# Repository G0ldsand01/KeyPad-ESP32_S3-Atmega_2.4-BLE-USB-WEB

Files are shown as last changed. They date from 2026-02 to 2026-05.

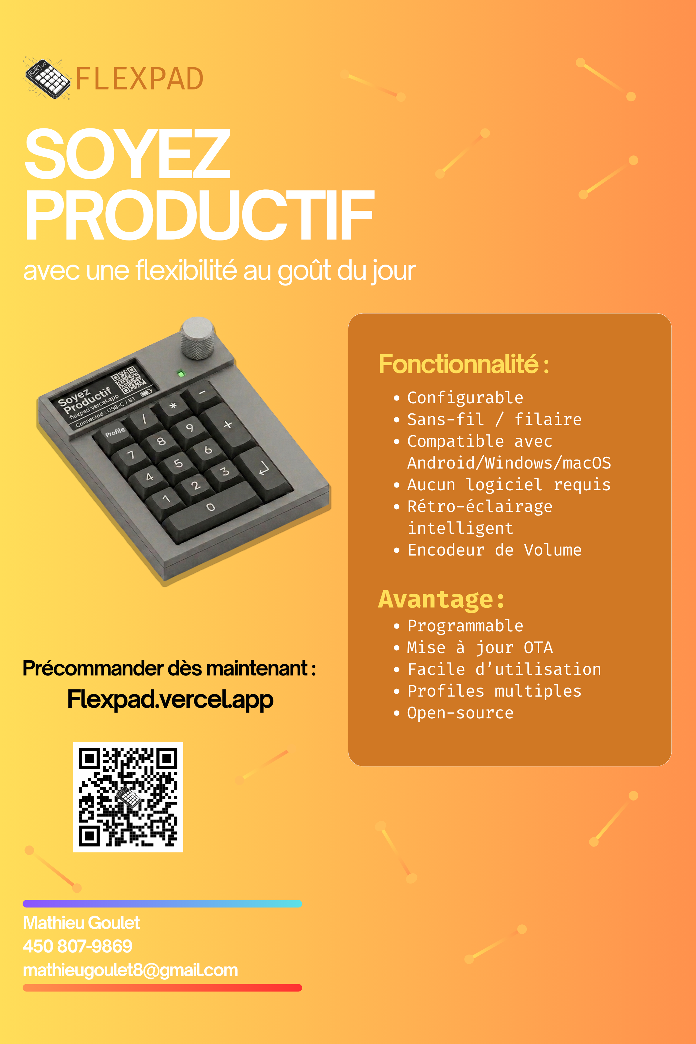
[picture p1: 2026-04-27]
public/images/Affiche.png

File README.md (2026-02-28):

# Macropad — Pavé numérique configurable

Projet de pavé numérique personnalisable avec ESP32-S3 et ATmega328P, configurable via une interface web moderne (Web Serial / Web Bluetooth).

## 📁 Structure du projet

```
Projet_Final/
├── README.md                 # Ce fichier — vue d'ensemble
├── docs/
│   └── FONCTIONNALITES.md    # Description détaillée des fonctions
├── firmware/                 # Code Arduino (ESP32) et C++ (ATmega)
│   └── README.md             # Guide firmware
├── PCB/                      # Schémas et circuits imprimés KiCad
│   └── README.md             # Documentation PCB
├── public/
│   ├── scripts/main.js       # Logique principale de l'interface
│   └── styles/global.css     # Styles CSS
├── src/
│   ├── components/           # NumpadGrid, ConfigPanel, BacklightPanel, SettingsPanel, etc.
│   ├── layouts/
│   └── pages/
├── package.json
└── astro.config.mjs
```

## 🚀 Démarrage rapide

### Interface web

```bash
pnpm install
pnpm dev
```

Ouvrez `http://localhost:4321`

### Connexion au Macropad

- **USB** : Sélectionnez "Wired (USB)" → Connecter → Choisir le port série
- **Bluetooth** : Sélectionnez "Bluetooth (ESP32)" → Connecter → Choisir l'appareil

### Firmware

Voir [firmware/README.md](./firmware/README.md) pour compiler et flasher l'ESP32 et l'ATmega.

## ✅ Ce qui fonctionne actuellement

| Fonctionnalité | Statut |
|---|---|
| Configuration des touches (simple, modificateur, média, macro) | ✅ |
| Profils multiples avec stockage flash ESP32 | ✅ |
| Connexion USB (Web Serial) | ✅ |
| Connexion Bluetooth (Web Bluetooth) | ✅ |
| Rétro-éclairage (luminosité, auto) | ✅ |
| Encodeur rotatif (volume, mute) | ✅ |
| OTA sans fil (mise à jour firmware via BLE/USB) | ✅ |
| Export/Import configuration JSON | ✅ |
| Moniteur série intégré | ✅ |
| Thème sombre/clair | ✅ |
| Matrice 5×4 (20 touches) | ✅ |

## ⚠️ À corriger / à améliorer

| Élément | Description |
|---|---|
| Dongle 2.4 GHz | Support WiFi/2.4 GHz non implémenté |
| Capteur d'empreinte | Composant DisplayPanel/FingerprintPanel présent mais non intégré aux onglets actifs |
| Écran OLED | Gestion côté firmware (ATmega) ; interface web partielle |
| Vérifier mises à jour | Bouton "Vérifier les mises à jour" (placeholder) |
| Compatibilité Firefox/Safari | Web Serial et Web Bluetooth non supportés |
| Tests automatisés | Pas de suite de tests |

## 📋 À faire

- [ ] Intégrer les onglets Display et Fingerprint si matériel connecté
- [ ] Implémenter la vérification des mises à jour OTA
- [ ] Support dongle 2.4 GHz (WiFi)
- [ ] Tests E2E pour l'interface web
- [ ] Documentation des APIs JSON pour développeurs

## 🛠️ Technologies

- **Frontend** : Astro 4, CSS, Lucide Icons
- **Communication** : Web Serial API, Web Bluetooth API
- **Firmware** : Arduino (ESP32-S3), C++ (ATmega328P)
- **PCB** : KiCad

## 📚 Documentation

- [Fonctionnalités détaillées](./docs/FONCTIONNALITES.md)
- [Firmware Arduino/ESP](./firmware/README.md)
- [PCB](./PCB/README.md)

## 📄 Licence

Projet académique — Cégep Gerald-Godin.

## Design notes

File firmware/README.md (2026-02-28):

# Firmware Macropad — Arduino & ESP32

Code source pour les microcontrôleurs du macropad : **ESP32-S3** (Arduino/C++) et **ATmega328P** (C++).

> Voir le [README principal](../README.md) pour la vue d'ensemble du projet.

## 📁 Structure

```
firmware/
├── esp32/
│   ├── esp32_micropython/           # Projet Arduino principal
│   │   ├── esp32_micropython.ino     # Point d'entrée
│   │   ├── Config.h                  # Pins, constantes, codes HID
│   │   ├── KeyMatrix.h/cpp           # Scan matrice 5×4
│   │   ├── Encoder.h/cpp             # Encodeur rotatif (volume)
│   │   ├── HidOutput.h/cpp           # HID USB + BLE
│   │   └── ARCHITECTURE.md           # Architecture du code
│   └── USB_CONNECTION.md             # Notes connexion USB
├── atmega/
│   └── atmega_light/                 # Projet Microchip Studio
│       ├── main.cpp                   # Code principal
│       └── atmega_light.cppproj       # Projet
└── README.md
```

## 🚀 Guide de Démarrage Rapide

### 1. ESP32-S3

#### Prérequis
- Arduino IDE installé
- Support ESP32 ajouté (voir `docs/README_ESP32.md`)

#### Étapes

1. **Installer les librairies** :
   - Ouvrez Arduino IDE
   - Allez dans **Croquis > Inclure une bibliothèque > Gérer les bibliothèques**
   - Installez :
   - **ArduinoJson** (version 6.x) - **ESSENTIEL**
   - **Adafruit NeoPixel** - LED built-in
   - Adafruit GFX, SSD1306, Fingerprint (si écran/empreinte utilisés)

2. **Ouvrir le code** :
   - Ouvrez `esp32/esp32_micropython/esp32_micropython.ino` dans Arduino IDE

3. **Configurer la carte** :
   - **Outils > Type de carte** : "ESP32S3 Dev Module"
   - **Outils > Port** : Sélectionnez le port COM de votre ESP32
   - **Outils > USB CDC On Boot** : "Enabled" (ou "Disabled" pour Android - voir section Android)
   - **Outils > USB Mode** : "Hardware CDC and JTAG"
   - **Outils > CPU Frequency** : "240MHz (WiFi/BT)"
   - **Outils > Flash Size** : "4MB (32Mb)"
   - **Outils > Partition Scheme** : "Default 4MB with spiffs" ou "Minimal SPIFFS (1.9MB APP with OTA)" pour OTA

4. **Compiler et téléverser** :
   - Cliquez sur **Vérifier** (✓) pour compiler
   - Si aucune erreur, cliquez sur **Téléverser** (→)
   - Attendez la fin du téléversement

5. **Vérifier** :
   - Ouvrez le **Moniteur série** (115200 bauds)
   - Vous devriez voir "=== ESP32-S3 Macropad Initialization ==="
   - L'écran OLED devrait afficher "Macropad Ready"

### 2. ATmega328P/168A

#### Prérequis
- Microchip Studio installé
- PICKit 4 connecté

#### Étapes

1. **Ouvrir le projet** :
   - Ouvrez `atmega/atmega_light/atmega_light.atsln` dans Microchip Studio
   - Ou créez un projet et ajoutez `atmega/atmega_light/main.cpp`

2. **Compiler** :
   - **Build > Build Solution** (F7)
   - Vérifiez qu'il n'y a pas d'erreurs

3. **Programmer** :
   - Connectez le PICKit 4 à l'ATmega
   - **Tools > Device Programming**
   - Sélectionnez "PICKit 4" et "ATmega328P"
   - Cliquez sur "Apply"
   - **Memories > Flash** : Sélectionnez le fichier `.hex` généré
   - Cliquez sur "Program"

4. **Vérifier** :
   - L'ATmega devrait répondre sur I2C à l'adresse 0x08
   - Utilisez un scanner I2C pour vérifier

## 🔧 ESP32-S3

### Fonctionnalités

- Communication USB HID (clavier)
- Communication Bluetooth (BLE)
- Communication I2C avec ATmega328P
- Gestion de l'écran OLED
- Gestion du capteur d'empreinte digitale
- Gestion du rétro-éclairage
- Gestion de l'encodeur rotatif
- **Stockage des profils en mémoire flash** (transfert entre appareils)

### Installation

1. Ouvrez `esp32/esp32_micropython/esp32_micropython.ino` dans Arduino IDE
2. Installez les librairies : ArduinoJson 6.x, Adafruit NeoPixel (voir section Prérequis)
3. Configurez la carte ESP32-S3
4. Téléversez le code

### Version Minimale

La version minimale du macropad ESP32-S3 gère directement une matrice 2x2 :

#### Configuration Matrice de Touches

La matrice 2x2 est gérée directement par l'ESP32-S3 :
- **GPIO 4** = Colonne 0
- **GPIO 5** = Colonne 1
- **GPIO 6** = Ligne 0
- **GPIO 7** = Ligne 1

#### Mapping des touches :
- Touche 0 : Ligne 0, Colonne 0 (index 0)
- Touche 1 : Ligne 0, Colonne 1 (index 1)
- Touche 2 : Ligne 1, Colonne 0 (index 2)
- Touche 3 : Ligne 1, Colonne 1 (index 3)

#### Configuration Encodeur Rotatif

L'encodeur rotatif pour le volume utilise :
- **GPIO 18** = CLK (Clock)
- **GPIO 19** = DT (Data)
- **GPIO 20** = SW (Switch/Bouton pour mute)

#### Fonctionnalités Version Minimale

1. ✅ Scan direct de la matrice 2x2
2. ✅ Gestion de l'encodeur rotatif (volume up/down)
3. ✅ Bouton de l'encodeur (mute)
4. ✅ Configuration des touches via Serial JSON
5. ✅ Sauvegarde des profils en mémoire flash
6. ✅ Support USB HID Keyboard
7. ✅ **USB Passthrough** — PROFILE+0 maintenu 3s bascule entre clavier et fingerprint (port USB A)

#### Non inclus (pour version complète) :
- Écran OLED
- Capteur d'empreinte
- Communication I2C avec ATmega
- Rétro-éclairage
- Consumer Control pour volume (actuellement envoie messages série)

### Stockage des Profils

Les profils sont stockés dans la **mémoire flash** de l'ESP32-S3 via l'API `Preferences`. Cela permet de :

- ✅ Conserver les profils même après redémarrage
- ✅ Transférer les profils entre différents appareils
- ✅ Sauvegarder automatiquement les modifications
- ✅ Ne pas dépendre de l'interface web pour la configuration

#### API Preferences

L'ESP32-S3 utilise l'API `Preferences` qui stocke les données dans la mémoire flash de manière persistante. Les données sont organisées en **namespace** et **clés**.

#### Structure de stockage

```
Namespace: "macropad"
├── profileCount (int)          : Nombre de profils
├── activeProfile (int)          : Index du profil actif
├── profile0 (string)           : Profil 0 (JSON)
├── profile1 (string)           : Profil 1 (JSON)
├── ...
├── profile9 (string)           : Profil 9 (JSON)
├── backlightOn (bool)          : Rétro-éclairage activé
├── backlightBr (int)           : Luminosité rétro-éclairage
├── autoBright (bool)           : Luminosité automatique
├── fingerOn (bool)             : Capteur d'empreinte activé
├── outputMode (string)         : Mode de sortie (usb/bluetooth/wifi)
├── displayBr (int)             : Luminosité écran
└── displayMode (string)        : Mode écran (data/image/gif)
```

#### Format JSON des profils

Chaque profil est stocké comme une chaîne JSON :

```json
{
  "name": "Profil 1",
  "keys": {
    "0-1": {
      "type": "key",
      "value": "ENTER"
    },
    "1-0": {
      "type": "key",
      "value": "c",
      "modifiers": ["CTRL"]
    },
    "2-1": {
      "type": "macro",
      "value": "",
      "macro": ["CTRL+C", "CTRL+V", "ENTER"],
      "delay": 50
    }
  }
}
```

#### Limites et contraintes

- **Limite par clé** : ~4000 bytes (Preferences API)
- **Nombre de profils** : 10 maximum
- **Touches par profil** : 20 maximum
- **Espace flash total** : Dépend de la partition (généralement plusieurs MB)

#### Synchronisation avec l'interface web

L'interface web envoie un message JSON complet. L'ESP32 :
1. Parse le JSON
2. Met à jour la configuration en mémoire
3. Sauvegarde dans la flash
4. Envoie une confirmation

## 🔧 ATmega328P/168A

### Fonctionnalités

- Scan de la matrice de touches 4×5
- Communication I2C en mode esclave
- Anti-rebond matériel/logiciel
- Scan périodique via timer

### Installation

1. Ouvrez `atmega/atmega_light/atmega_light.atsln` dans Microchip Studio
2. Compilez (F7)
3. Programmez avec PICKit 4 (Tools > Device Programming)

### Communication I2C

- **Adresse** : 0x08
- **Fréquence** : 100 kHz
- **Format** : 2 bytes (LSB, MSB) représentant l'état des 16 touches

## 🌐 Compatibilité Multi-Plateforme

Le macropad ESP32-S3 est conçu pour être compatible avec **Windows, macOS, Linux, iOS et Android**.

### Modes de Connexion

#### USB HID (Windows, macOS, Linux)
- **Connexion** : Câble USB-C
- **Reconnaissance** : Automatique, aucun pilote nécessaire
- **Fonctionnalités** : Toutes les touches et macros fonctionnent
- **Volume** : FN+F1/F2/F3 (fonctionne sur Windows et macOS)

#### Bluetooth HID (iOS, Android)
- **Connexion** : Bluetooth Low Energy (BLE)
- **Reconnaissance** : Appareil visible comme "Macropad"
- **Fonctionnalités** : Toutes les touches et macros fonctionnent
- **Volume** : FN+F1/F2/F3 (fonctionne sur iOS et Android)

### Compatibilité par Plateforme

#### ✅ Windows
- **Mode** : USB HID
- **Pilotes** : Aucun nécessaire (HID standard)
- **Test** : Ouvrez le Bloc-notes et appuyez sur les touches
- **Volume** : FN+F3 (Volume Up), FN+F2 (Volume Down), FN+F1 (Mute)

#### ✅ macOS
- **Mode** : USB HID
- **Pilotes** : Aucun nécessaire (HID standard)
- **Test** : Ouvrez TextEdit et appuyez sur les touches
- **Volume** : FN+F3 (Volume Up), FN+F2 (Volume Down), FN+F1 (Mute)
- **Note** : KEY_LEFT_GUI devient automatiquement Cmd sur macOS

#### ✅ Linux
- **Mode** : USB HID
- **Pilotes** : Aucun nécessaire (HID standard)
- **Test** : Ouvrez un éditeur de texte et appuyez sur les touches
- **Volume** : Peut nécessiter une configuration système pour FN+F1/F2/F3

#### ✅ iOS (iPhone/iPad)
- **Mode** : Bluetooth HID (BLE)
- **Activation** : Décommentez `#define USE_BLE_KEYBOARD` dans le code
- **Connexion** :
  1. Activez Bluetooth sur votre iPhone/iPad
  2. Allez dans Réglages > Bluetooth
  3. Recherchez "Macropad"
  4. Appuyez sur "Macropad" pour vous connecter
- **Test** : Ouvrez Notes et appuyez sur les touches
- **Volume** : FN+F3/F2/F1 fonctionne sur iOS

#### ✅ Android

Le macropad ESP32-S3 fonctionne directement en USB HID sur Android via USB-C (USB OTG).

**Compatibilité Android** :
- **Pixel 10** : ✅ Compatible
- **Autres appareils Android** : Compatible si USB OTG est supporté

**Connexion USB** :
1. **Branchez le macropad** à votre appareil Android avec un câble USB-C vers USB-C
2. **Android détecte automatiquement** le périphérique comme clavier HID
3. **Aucune configuration nécessaire** - fonctionne immédiatement

**Configuration Arduino IDE pour Android** :
- **USB CDC On Boot** : **Disabled** ⚠️ IMPORTANT
  - Si activé, cela crée un conflit avec USB HID
  - Android ne reconnaîtra pas le périphérique correctement
- **USB Mode** : **Hardware CDC and JTAG** ou **Native USB**
- **USB DFU On Boot** : **Disabled**
- **USB Firmware MSC On Boot** : **Disabled**

**Activation USB OTG sur Android** :
Sur certains appareils Android, vous devez activer le mode USB OTG :
1. Allez dans **Paramètres**
2. Recherchez **USB** ou **Connexions**
3. Activez **USB OTG** ou **Mode hôte USB**

**Note** : Sur Pixel 10 et les appareils récents, USB OTG est généralement activé par défaut.

**Connexion Bluetooth** :
1. Activez Bluetooth sur votre appareil Android
2. Allez dans Paramètres > Bluetooth
3. Recherchez "Macropad"
4. Appuyez sur "Macropad" pour vous connecter

**Test** : Ouvrez une application de notes et appuyez sur les touches
**Volume** : FN+F3/F2/F1 fonctionne sur Android

### Configuration

#### Activer le Mode Bluetooth

Pour activer le support Bluetooth HID (nécessaire pour iOS/Android) :

1. Ouvrez `esp32_micropython.ino`
2. Trouvez la ligne :
   ```cpp
   // #define USE_BLE_KEYBOARD
   ```
3. Décommentez-la :
   ```cpp
   #define USE_BLE_KEYBOARD
   ```
4. Installez la bibliothèque **BleKeyboard** :
   - Arduino IDE > Croquis > Inclure une bibliothèque > Gérer les bibliothèques
   - Recherchez "BleKeyboard" par T-vK
   - Installez la bibliothèque
5. Recompilez et téléversez

#### Basculer entre USB et Bluetooth

Le macropad détecte automatiquement :
- **USB** : Si connecté via USB, utilise USB HID
- **Bluetooth** : Si Bluetooth est activé et connecté, utilise Bluetooth HID

Vous pouvez aussi forcer un mode dans le code en modifiant :
```cpp
String outputMode = "usb";  // ou "bluetooth"
```

#### USB Hub (clavier + fingerprint simultanés)

Avec le hub USB2514, le clavier et le fingerprint fonctionnent en même temps — pas de bascule manuelle.

#### BLE Switch appareil (PROFILE + 1)

Pour basculer entre plusieurs appareils Bluetooth (PC, téléphone, tablette) :

1. **Maintenez** PROFILE + 1 pendant **2 secondes**
2. Le Macropad se déconnecte et redémarre l'advertising
3. Connectez-vous depuis l'autre appareil (Paramètres Bluetooth)

### Codes de Touches Compatibles

Tous les codes de touches HID standard sont compatibles :
- Lettres : a-z, A-Z
- Chiffres : 0-9
- Modificateurs : CTRL, SHIFT, ALT, GUI (Windows/Cmd)
- Touches spéciales : ENTER, SPACE, TAB, ESC, BACKSPACE, DELETE
- Flèches : UP, DOWN, LEFT, RIGHT
- Fonctions : F1-F12

### Contrôle du Volume

Le contrôle du volume utilise des combinaisons de touches compatibles avec tous les systèmes :

- **Volume Up** : FN + F3 (KEY_LEFT_GUI + KEY_F3)
- **Volume Down** : FN + F2 (KEY_LEFT_GUI + KEY_F2)
- **Mute** : FN + F1 (KEY_LEFT_GUI + KEY_F1)

**Note** : Sur macOS, KEY_LEFT_GUI devient automatiquement Cmd, donc :
- Volume Up = Cmd + F3
- Volume Down = Cmd + F2
- Mute = Cmd + F1

Sur iOS et Android, ces combinaisons fonctionnent via Bluetooth HID.

## 📝 Notes importantes

### Mise à jour OTA (sans fil)

L'interface web permet de flasher le firmware **sans fil** via BLE ou USB Serial. Le fichier `.bin` est envoyé par chunks, décodé (base64) et écrit dans la partition OTA de l'ESP32.

**Prérequis :**
- Schéma de partition avec OTA (ex: "Default 4MB with spiffs" ou "Minimal SPIFFS (1.9MB APP with OTA)")
- Exporter le binaire : Arduino IDE > Croquis > Exporter le binaire compilé

**Utilisation :**
1. Connectez-vous via BLE ou USB
2. Onglet Paramètres > Mise à jour OTA
3. Sélectionnez le fichier `.bin` compilé
4. Cliquez sur "Mettre à jour le firmware"
5. Ne déconnectez pas pendant le transfert

### Pour ESP32-S3

- Le code utilise une version simplifiée du parsing JSON
- Pour la production, utilisez la librairie **ArduinoJson** pour un parsing complet
- Les touches média nécessitent la librairie **ConsumerControl**
- Le code est optimisé pour la compatibilité avec l'interface web
- **ArduinoJson est OBLIGATOIRE** : Sans cette librairie, le parsing JSON ne fonctionnera pas
- Les profils sont sauvegardés automatiquement dans la flash
- Vous pouvez déconnecter et reconnecter, les profils seront conservés

### Pour ATmega328P/168A

- Le scan est fait via interruption timer (10ms)
- La communication I2C est gérée par interruption
- Les résistances de pull-down sont nécessaires sur les colonnes
- Les résistances de pull-up (4.7kΩ) sont nécessaires sur SDA/SCL
- L'adresse I2C est fixée à 0x08 dans le code

## 🔄 Synchronisation avec l'interface web

L'interface web envoie la configuration complète au format JSON. L'ESP32 :

1. Reçoit le message JSON
2. Parse la configuration
3. Sauvegarde dans la mémoire flash
4. Applique la configuration immédiatement

Lors du démarrage, l'ESP32 :

1. Charge la configuration depuis la mémoire flash
2. Envoie un message de statut à l'interface web
3. Prêt à recevoir de nouvelles configurations

## 🐛 Dépannage

### ESP32 ne sauvegarde pas les profils

- Vérifiez que `Preferences.begin()` est appelé
- Vérifiez l'espace disponible en mémoire flash
- Utilisez `preferences.clear()` pour réinitialiser si nécessaire
- Vérifiez que le JSON n'est pas trop grand (>4000 bytes)

### ATmega ne répond pas sur I2C

- Vérifiez les connexions SDA/SCL
- Vérifiez les résistances de pull-up
- Utilisez un scanner I2C pour vérifier l'adresse

### Les touches ne sont pas détectées

- Vérifiez les connexions de la matrice
- Vérifiez les résistances de pull-down
- Testez chaque ligne/colonne individuellement

### ESP32 ne compile pas

- Vérifiez que toutes les librairies sont installées
- Vérifiez que ArduinoJson est bien installé (version 6.x)
- Vérifiez que le support ESP32 est à jour

### Le macropad n'est pas reconnu sur Android

1. **Vérifiez le câble** :
   - Utilisez un câble USB-C vers USB-C de données (pas seulement charge)
   - Essayez un autre câble si possible

2. **Vérifiez USB OTG** :
   - Activez USB OTG dans les paramètres Android
   - Sur certains appareils, c'est dans Paramètres > Système > Options développeur

3. **Vérifiez la configuration Arduino IDE** :
   - USB CDC On Boot doit être **Disabled**
   - Recompilez et téléversez le code

4. **Redémarrez l'appareil Android** :
   - Parfois Android a besoin d'un redémarrage pour reconnaître un nouveau périphérique USB

5. **Vérifiez les notifications Android** :
   - Android peut afficher une notification "Périphérique USB connecté"
   - Appuyez dessus et sélectionnez "Clavier" ou "HID"

### Le macropad est reconnu mais les touches ne fonctionnent pas

1. **Vérifiez que vous êtes dans une zone de texte** :
   - Ouvrez une application avec un champ de texte (Notes, Messages, etc.)
   - Cliquez dans le champ de texte avant d'appuyer sur les touches

2. **Vérifiez la configuration des touches** :
   - Par défaut, les touches envoient "1", "2", "3", "4"
   - Configurez-les via l'interface web si nécessaire

3. **Testez avec un autre appareil** :
   - Testez sur un ordinateur Windows/macOS pour vérifier que le macropad fonctionne
   - Si ça fonctionne sur PC mais pas Android, c'est un problème Android spécifique

### Erreur Code 43 sur Windows

**Erreur** : "Windows a arrêté ce périphérique, car il présente des problèmes. (Code 43)"

Cette erreur indique que Windows ne peut pas lire le descripteur USB HID correctement.

#### Solutions à essayer dans l'ordre

1. **Configuration Arduino IDE** :
   - **USB CDC On Boot** : **Disabled** ⚠️ IMPORTANT
     - Si activé, cela crée un conflit avec USB HID
     - Le périphérique essaie d'être à la fois Serial et HID, ce qui cause l'erreur
   - **USB Mode** : **Hardware CDC and JTAG** ou **Native USB**
   - **USB DFU On Boot** : **Disabled**
   - **USB Firmware MSC On Boot** : **Disabled**

2. **Réinitialiser le périphérique USB dans Windows** :
   - Ouvrez le **Gestionnaire de périphériques** (Win+X > Gestionnaire de périphériques)
   - Trouvez le périphérique ESP32-S3 (peut apparaître comme "Unknown Device" ou avec un point d'exclamation)
   - **Clic droit > Désinstaller le périphérique**
   - Cochez "Supprimer le pilote" si l'option est disponible
   - Débranchez et rebranchez l'ESP32-S3
   - Windows devrait réinstaller le pilote automatiquement

3. **Installer les pilotes USB ESP32** :
   - Téléchargez les pilotes depuis : https://github.com/espressif/usb-pid
   - Ou utilisez le gestionnaire de pilotes Windows Update
   - Redémarrez l'ordinateur après l'installation

4. **Vérifier les pins utilisés** :
   - **IMPORTANT** : Ne pas utiliser GPIO 19 et 20 pour d'autres périphériques !
   - GPIO 19 = USB_D- (négatif USB)
   - GPIO 20 = USB_D+ (positif USB)
   - Ces pins sont réservés pour la communication USB native.

5. **Tester avec un code minimal** :
   ```cpp
   #include <USB.h>
   #include <USBHIDKeyboard.h>
   
   USBHIDKeyboard Keyboard;
   
   void setup() {
       USB.begin();
       delay(1000);
       Keyboard.begin();
       delay(1000);
   }
   
   void loop() {
       delay(1000);
       Keyboard.print("Test");
   }
   ```
   Si ce code fonctionne, le problème vient de votre code principal.

6. **Vérifier le câble USB** :
   - Utilisez un **câble USB-C de données** (pas seulement charge)
   - Essayez un autre câble
   - Essayez un autre port USB (de préférence USB 2.0)

7. **Désactiver temporairement Serial** :
   - Si vous utilisez Serial en même temps que USB HID, cela peut causer un conflit.
   - Dans le code, commentez temporairement :
     ```cpp
     // Serial.begin(115200);
     // Serial.println("...");
     ```
   - Et testez si l'erreur disparaît.

8. **Réinitialiser l'ESP32-S3** :
   - Appuyez sur le bouton **BOOT** (ou **RST**) pendant le téléversement
   - Relâchez après le début du téléversement
   - Attendez la fin du téléversement
   - Appuyez sur **RST** pour redémarrer

9. **Vérifier la version d'Arduino ESP32** :
   - **Outils > Type de carte > Gestionnaire de cartes**
   - Recherchez "esp32"
   - Mettez à jour vers la dernière version si nécessaire

10. **Test sur un autre ordinateur** :
    - Si possible, testez sur un autre ordinateur pour déterminer si c'est un problème Windows ou matériel.

#### Configuration recommandée Arduino IDE

```
Type de carte : ESP32S3 Dev Module
USB CDC On Boot : Disabled ⚠️
USB Mode : Hardware CDC and JTAG
USB DFU On Boot : Disabled
USB Firmware MSC On Boot : Disabled
CPU Frequency : 240MHz (WiFi/BT)
Flash Size : 4MB (32Mb)
Partition Scheme : Default 4MB with spiffs
PSRAM : OPI PSRAM (si disponible)
```

#### Vérification du périphérique

Après le téléversement, dans le Gestionnaire de périphériques, vous devriez voir :
- **Périphériques d'entrée > Clavier HID** (ou similaire)
- Pas de point d'exclamation jaune
- Pas d'erreur Code 43

#### Notes importantes

- L'ordre d'initialisation dans `setup()` est critique
- USB.begin() doit être appelé AVANT Keyboard.begin()
- Attendre suffisamment longtemps entre les initialisations (1000ms minimum)
- Ne pas utiliser Serial.begin() en même temps que USB HID si possible

### Le macropad ne fonctionne pas sur iOS/Android

- Vérifiez que `USE_BLE_KEYBOARD` est activé
- Vérifiez que la bibliothèque BleKeyboard est installée
- Vérifiez que Bluetooth est activé sur l'appareil
- Vérifiez que l'appareil est appairé

### Le volume ne fonctionne pas

- Sur Windows/macOS : Vérifiez que les raccourcis système sont configurés
- Sur iOS/Android : Vérifiez que Bluetooth HID est activé et connecté
- Testez avec un éditeur de texte pour voir si les touches F1/F2/F3 fonctionnent

### Le macropad fonctionne en USB mais pas en Bluetooth

- Vérifiez que `USE_BLE_KEYBOARD` est activé
- Vérifiez que la bibliothèque BleKeyboard est installée
- Vérifiez que l'ESP32-S3 a le Bluetooth activé (CPU Frequency doit inclure BT)

## 📚 Ressources

- [Documentation ESP32 Preferences](https://docs.espressif.com/projects/esp-idf/en/latest/esp32/api-reference/storage/nvs_flash.html)
- [ArduinoJson Library](https://arduinojson.org/)
- [Documentation ATmega328P I2C](https://ww1.microchip.com/downloads/en/DeviceDoc/Atmel-7810-Automotive-Microcontrollers-ATmega328P_Datasheet.pdf)
- [Documentation ESP32-S3](https://docs.espressif.com/projects/esp-idf/en/latest/esp32s3/)
- [Arduino ESP32](https://github.com/espressif/arduino-esp32)
- [ESP32 BLE Keyboard](https://github.com/T-vK/ESP32-BLE-Keyboard)
- [Adafruit SSD1306](https://github.com/adafruit/Adafruit_SSD1306)
- [ESP32 Preferences API](https://docs.espressif.com/projects/arduino-esp32/en/latest/api/preferences.html)
- [ESP32 Flash Memory](https://docs.espressif.com/projects/esp-idf/en/latest/esp32/api-guides/partition-tables.html)

## ✅ Checklist de vérification

- [ ] ESP32-S3 compilé et téléversé
- [ ] ATmega328P/168A compilé et programmé
- [ ] Interface web accessible
- [ ] Connexion USB établie
- [ ] Premier profil créé et sauvegardé
- [ ] Touches testées et fonctionnelles
- [ ] Écran OLED affiche les informations
- [ ] Rétro-éclairage fonctionne

Une fois tous les éléments cochés, votre macropad est prêt à l'emploi ! 🎉

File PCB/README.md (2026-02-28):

# PCB Macropad

Circuits imprimés et schémas du pavé numérique, conçus avec KiCad.

> Voir le [README principal](../README.md) pour la vue d'ensemble du projet.

## 📁 Fichiers

| Fichier | Description |
|---|---|
| `numberpad.kicad_pro` | Projet KiCad |
| `numberpad.kicad_pcb` | Carte PCB |
| `numberpad.kicad_sch` | Schéma électrique |
| `LED.kicad_sch` | Sous-schéma LED |
| `Switch.kicad_sch` | Sous-schéma switch |
| `bom/ibom.html` | BOM interactif |

## 🔧 Composants principaux

- **ESP32-S3-WROOM-2** : Microcontrôleur principal (16 MB Flash, 8 MB PSRAM)
- **ATmega328P** : Scan matrice touches (optionnel, selon version)
- **Switches** : Gateron KS-33 Low Profile 2.0
- **Encodeur rotatif** : Volume + bouton mute
- **LED** : NeoPixel ou rétro-éclairage
- **Connecteurs** : USB-C, écran, capteur empreinte

## 📐 Spécifications

- **Format** : À définir selon version (voir fichiers KiCad)
- **Couches** : 2 (typique pour prototype)
- **Finition** : À préciser pour fabrication

## 🛠️ Ouverture du projet

1. Installer [KiCad](https://www.kicad.org/)
2. Ouvrir `numberpad.kicad_pro`
3. Schéma : `numberpad.kicad_sch`
4. PCB : `numberpad.kicad_pcb`

## 📦 Fabrication

1. Exporter les fichiers Gerber depuis KiCad (Fichier > Plot)
2. Exporter le fichier de perçage (Excellon)
3. Envoyer à un fabricant (JLCPCB, PCBWay, etc.)

## ⚠️ Notes

- Vérifier les empreintes (footprints) avant fabrication
- Le BOM interactif (`bom/ibom.html`) aide à la pose des composants
- Adapter les chemins des modèles 3D si nécessaire

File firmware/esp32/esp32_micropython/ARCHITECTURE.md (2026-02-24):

# Architecture du firmware — Macropad ESP32-S3

Inspiré de [MacroPad (aayushchouhan24)](https://github.com/aayushchouhan24/MacroPad) :

- **Logique modulaire** — KeyMatrix, Encoder, HidOutput
- **Logique événementielle** — callbacks sur chaque entrée
- **HID standalone** — fonctionne sur tout appareil sans app (phone, PC)

## Structure des fichiers

```
esp32_micropython/
├── Config.h          # Pins, constantes, codes HID
├── KeyMatrix.h/cpp   # Scan matrice 5×4, debounce, répétition
├── Encoder.h/cpp     # Encodeur rotatif (volume) + bouton (mute)
├── HidOutput.h/cpp   # Envoi HID (BLE + USB)
└── esp32_micropython.ino  # Setup, loop, callbacks, BLE, UART, web
```

## Flux d’événements

```
KeyMatrix.scan()  → debounce → onKeyPress(row, col, pressed, isRepeat)
                           → HidOutput.sendKey(symbol, row, col)
                           → BLE ou USB HID

Encoder.update()  → onEncoderRotate(dir)  → HidOutput.sendVolumeUp/Down()
                 → onEncoderButton(pressed) → HidOutput.sendMute()
```

## Différence avec MacroPad (aayushchouhan24)

| MacroPad | Ce projet |
|---|---|
| ESP32 envoie des événements bruts (index touche) | ESP32 envoie directement les rapports HID |
| App PC traduit les événements en touches | Aucune app requise |
| Ne fonctionne pas sur téléphone | Fonctionne sur téléphone, PC, etc. |

## Configuration

- **Keymap** : définie dans `KEYMAP` (chargée depuis `DEFAULT_KEYMAP` ou via l’interface web)
- **Config** : via Web Serial / Web Bluetooth (JSON)

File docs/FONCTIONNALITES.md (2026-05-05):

# Fonctionnalités du Macropad

Description détaillée des fonctions de l'interface web et du firmware.

> Voir le [README principal](../README.md) pour la vue d'ensemble du projet.

## Interface web

### Onglet Principal

#### Pavé numérique (NumpadGrid)

- **Grille 5×4** : 20 touches configurables
- **Touche PROFILE (0-0)** : Change de profil (Profil 1, Configuration, etc.)
- **Sélection** : Cliquer sur une touche pour la configurer
- **Feedback visuel** : Touches configurées en vert, touche sélectionnée en bleu

#### Configuration des touches (ConfigPanel)

| Type | Description |
|---|---|
| **Touche simple** | Une touche (a, ENTER, SPACE, etc.) |
| **Modificateur** | CTRL, SHIFT, ALT, GUI (Windows/Cmd) |
| **Média** | Volume +/-, Mute, Play/Pause, Suivant, Précédent |
| **Macro** | Séquence de touches avec délai (ex: CTRL+C, CTRL+V, ENTER) |

**Presets média** : Volume +, Volume -, Mute, Play/Pause, Suivant, Précédent, Stop, Autre

#### Profils

- Création et suppression de profils
- Profil "Configuration" : touches de navigation partagées
- Stockage persistant dans la flash ESP32 (transfert entre appareils)
- Sauvegarde automatique à chaque modification

### Onglet Rétro-éclairage

- **Luminosité** : Slider 0–100 %
- **Selon l'environnement** : Ajustement automatique via capteur de lumière (ATmega)
- **État** : Affichage du niveau de lumière détecté

### Onglet Paramètres

#### Moniteur série (USB)

- Affichage de la sortie Serial de l'ESP32
- Défilement auto, max lignes (100–1000)
- Bouton Effacer

#### Connexion

- **Nom BLE** : Nom de l'appareil Bluetooth
- **Thème** : Sombre, Clair, Système

#### Debug & Logging

- Debug ESP32, Logging ESP32, Logging ATmega
- Niveaux de log : Aucun, Erreurs, Avertissements, Info, Debug, Verbose

#### Options de debug

- HID, I2C, Web UI, Display, Config

#### Mise à jour OTA

- Flasher le firmware sans fil via BLE ou USB
- Fichier `.bin` exporté depuis Arduino IDE
- Barre de progression, redémarrage automatique

#### Données

- **Exporter la configuration** : Télécharge un fichier JSON
- **Importer la configuration** : Charge un JSON exporté
- **Réinitialiser les paramètres** : Remet les paramètres par défaut

#### Appliquer

- Bouton "Appliquer les paramètres" pour envoyer la config à l'ESP32

## Firmware ESP32

### Matrice de touches

- **Pins** : Rows 4,5,6,7,15 ; Cols 16,17,18,8
- **Debounce** : 25 ms
- **Répétition** : 500 ms délai, 50 ms intervalle

### Encodeur rotatif

- **Volume** : Rotation = Volume +/- (Consumer Control ou HID)
- **Mute** : Bouton = Mute
- **Pins** : CLK=3, DT=46, SW=9

### BLE

- **Switch appareil** : PROFILE + 1 maintenu 2 s → déconnecte et permet de connecter un autre appareil
- **UUID** : Service 0xFFE0, Caractéristique 0xFFE1

### Communication ATmega (UART)

- **TX** : GPIO 10 → ATmega RX
- **RX** : GPIO 11 ← ATmega TX (diviseur 2k2/3k3 pour 5V→3.3V)
- **Baud** : 57600 (ATmega328P : mode double vitesse USART, `U2X`)

### Commandes ATmega

| Cmd | Description |
|-----|---|
| 0x01 | Lire capteur de lumière |
| 0x02 | Définir LED |
| 0x03 | Obtenir état LED |
| 0x04 | Mettre à jour l'écran |
| 0x05 | Données écran |
| 0x08 | Image écran |
| 0x09 | Chunk image |
| 0x0A | Debug ATmega |
| 0x0B | Niveau log ATmega |
| 0x0C | Dernière touche pressée |

## Firmware ATmega

- **Matrice** : Scan 4×5 via I2C ou direct
- **I2C** : Adresse 0x08, 100 kHz
- **Capteur lumière** : ADC pour rétro-éclairage auto
- **Écran** : ST7789 ou compatible, données via UART

## Protocole JSON (Web ↔ ESP32)

### Messages envoyés par l'interface

- `config` : Configuration complète (profils, keys)
- `backlight` : Rétro-éclairage
- `display_*` : Écran
- `ota_start`, `ota_chunk`, `ota_end` : Mise à jour OTA
- `get_light` : Demande niveau lumière
- `set_device_name` : Nom BLE

### Messages reçus de l'ESP32

- `status` : État de connexion
- `config` : Config actuelle
- `keypress` : Touche pressée
- `ota_status` : Progression OTA
- `uart_log` : Log série ATmega
- `light` : Niveau lumière

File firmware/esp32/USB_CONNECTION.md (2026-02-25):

# Connexion USB ESP32-S3 — Guide

## Garder le port série connecté

### 1. Paramètres Arduino IDE

Dans **Outils** (Tools) :

- **USB CDC On Boot** : **Enabled** (obligatoire pour voir le Serial)
- **USB Mode** : **Hardware CDC and JTAG** (pour ESP32-S3 DevKit avec USB-JTAG)
- **Carte** : **ESP32S3 Dev Module**

### 2. Utiliser le moniteur série intégré (Web UI)

Le Web UI inclut un **moniteur série** dans l’onglet **Paramètres**. Une fois connecté en USB :

1. Connectez-vous via **Connecter (USB)**
2. Ouvrez l’onglet **Paramètres**
3. La sortie `Serial.println()` de l’ESP32 s’affiche dans la zone « Moniteur série »

**Avantage** : pas besoin d’Arduino IDE ni de maintenir le bouton BOOT. Une seule application utilise le port.

### 3. Conflit avec Arduino IDE / moniteur série

Un port série ne peut être ouvert que par **une seule** application à la fois :

- Si le **Web UI** est connecté → fermez le moniteur série de l’Arduino IDE
- Si l’**Arduino IDE** utilise le port → déconnectez-vous du Web UI avant d’ouvrir le moniteur série

### 4. Si la connexion se coupe (« device lost »)

- Utilisez un **câble USB data** (certains câbles ne font que la charge)
- Branchez directement sur un **port USB du PC**, pas via un hub
- Vérifiez l’**alimentation** (5 V stable)
- Sur certaines cartes : un **jumper** désactive le reset automatique (DTR→EN) — voir la doc de la carte

### 5. Bouton BOOT

Le bouton **BOOT** est nécessaire **uniquement pour flasher** (mettre à jour le firmware). Pour la communication série normale, vous n’avez pas besoin de le maintenir.

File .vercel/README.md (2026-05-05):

# Dossier `.vercel` (local + CI)

## `output/`

Généré par `astro build` (adapter Vercel) + patch runtime. **Il est ignoré par Git**
(`.gitignore` : `.vercel/output/`).

Avant chaque `pnpm run build`, le script `prebuild` **efface** ce dossier pour éviter :

- un `vercel deploy --prebuilt` qui repousse d’anciens fichiers ;
- des incohérences après `git pull` si le build n’a pas tout régénéré.

## Lien projet (`project.json`)

Si tu déploies depuis la machine avec la CLI :

```bash
pnpm dlx vercel link
```

Ça crée / met à jour `.vercel/project.json` (souvent **non commité**).  
Les déploiements déclenchés par **push GitHub → Vercel** n’ont pas besoin de ce fichier.

## En prod les changements « ne partent pas »

1. Vérifie sur Vercel que le dernier **Deployment** correspond bien au commit poussé.
2. N’utilise pas `vercel deploy --prebuilt` avec un vieux `.vercel/output`.
3. Les en-têtes `Cache-Control: no-store` sur `/scripts/` sont dans `vercel.json`.

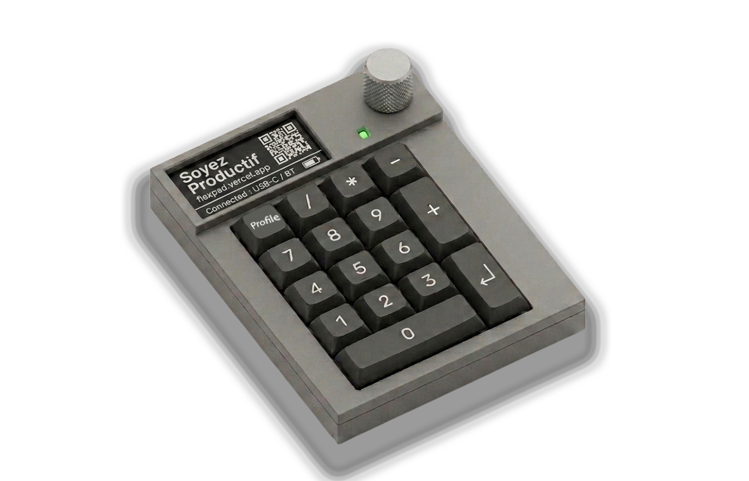
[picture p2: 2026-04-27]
public/images/Viewer1.png

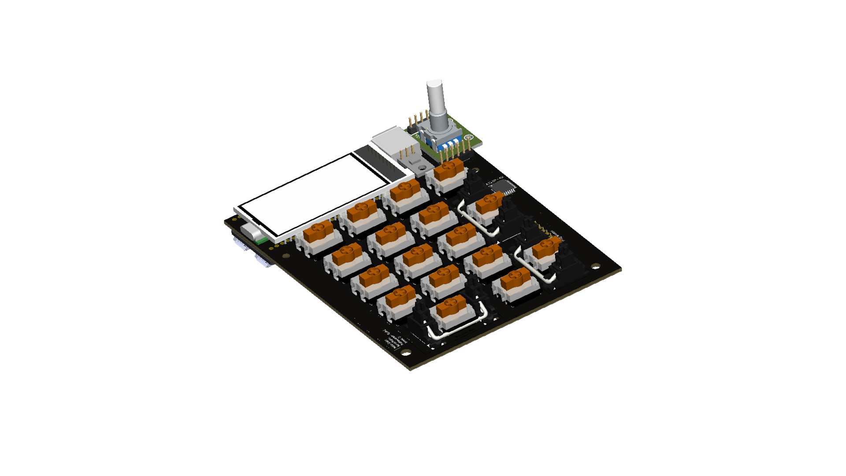
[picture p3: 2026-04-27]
public/images/top-view-pcb.png

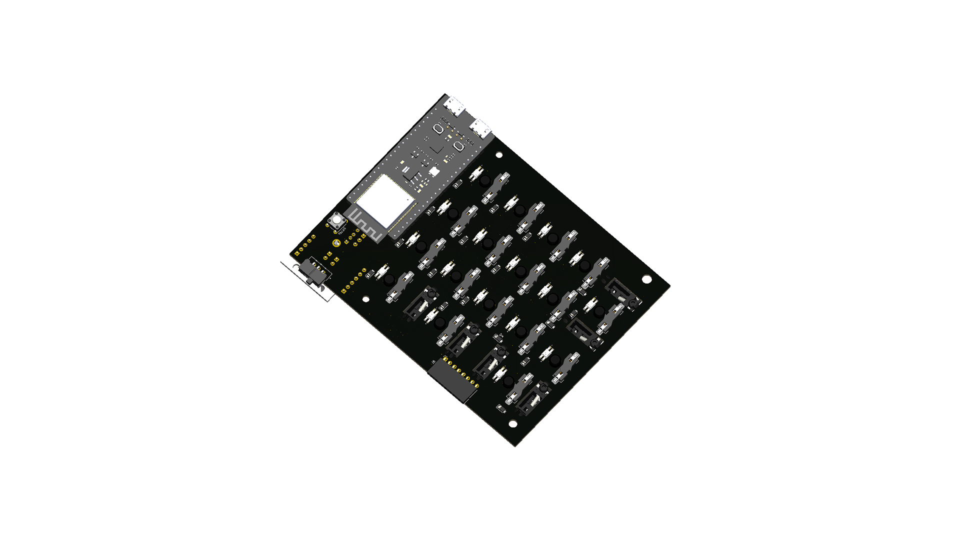
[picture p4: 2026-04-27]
public/images/under-view-pcb.png

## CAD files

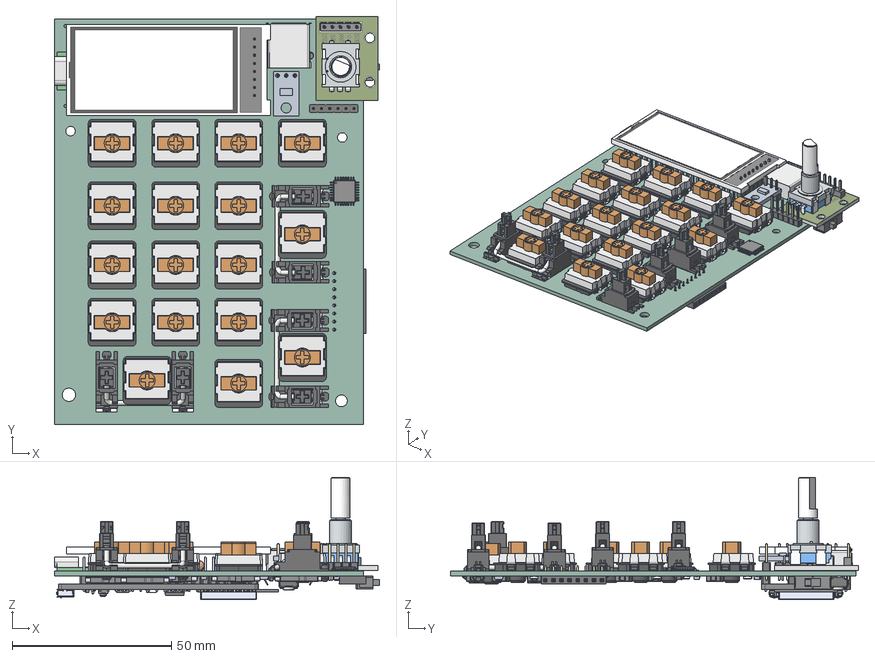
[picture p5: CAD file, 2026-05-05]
PCB/numpad_v1.1.step
102.0 x 128.1 x 38.4 mm
Stabilizer_Cherry_MX_2.00u x 3
usb_a-usbsa
Base x 17
Stem x 17
Cap x 17
PinA x 17
PinB x 17
Gateron_ks33_hotswap_socket x 17
PinHeader_1x04_P2.54mm_Vertical
USB-C 3.1 Connector Breakout Board v5
PinHeader_1x02_P2.54mm_Vertical x 2
R_Axial_DIN0204_L3.6mm_D1.6mm_P7.62mm_Horizontal x 2
C_Disc_D3.0mm_W1.6mm_P2.50mm x 2
SQFN36_6X6_MCH
PinHeader_1x06_P2.54mm_Vertical
PinHeader_1x03_P2.54mm_Vertical
TEMT6000
PinHeader_1x08_P2.54mm_Vertical
display320x240
ATMEGA328P-AU
PinHeader_1x05_P2.54mm_Vertical
pcb
mtg flange
body_encoder
5 pin header
decal_encoder
pins_encoder body_2 x 5
shaft_encoder
pins_encoder body_2_2 x 2
Crystal_HC49-4H_Vertical
SK6812-E x 17
numpad_v1.1 1.59.1 x 17
SW_TH_Tactile_Omron_B3F-100x
ESP32-S3-DEVKITC-1-N16R8V
MINI-SPDT-SW
PinSocket_1x08_P2.54mm_Horizontal
numberpad_PCB

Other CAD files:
PCB/.step

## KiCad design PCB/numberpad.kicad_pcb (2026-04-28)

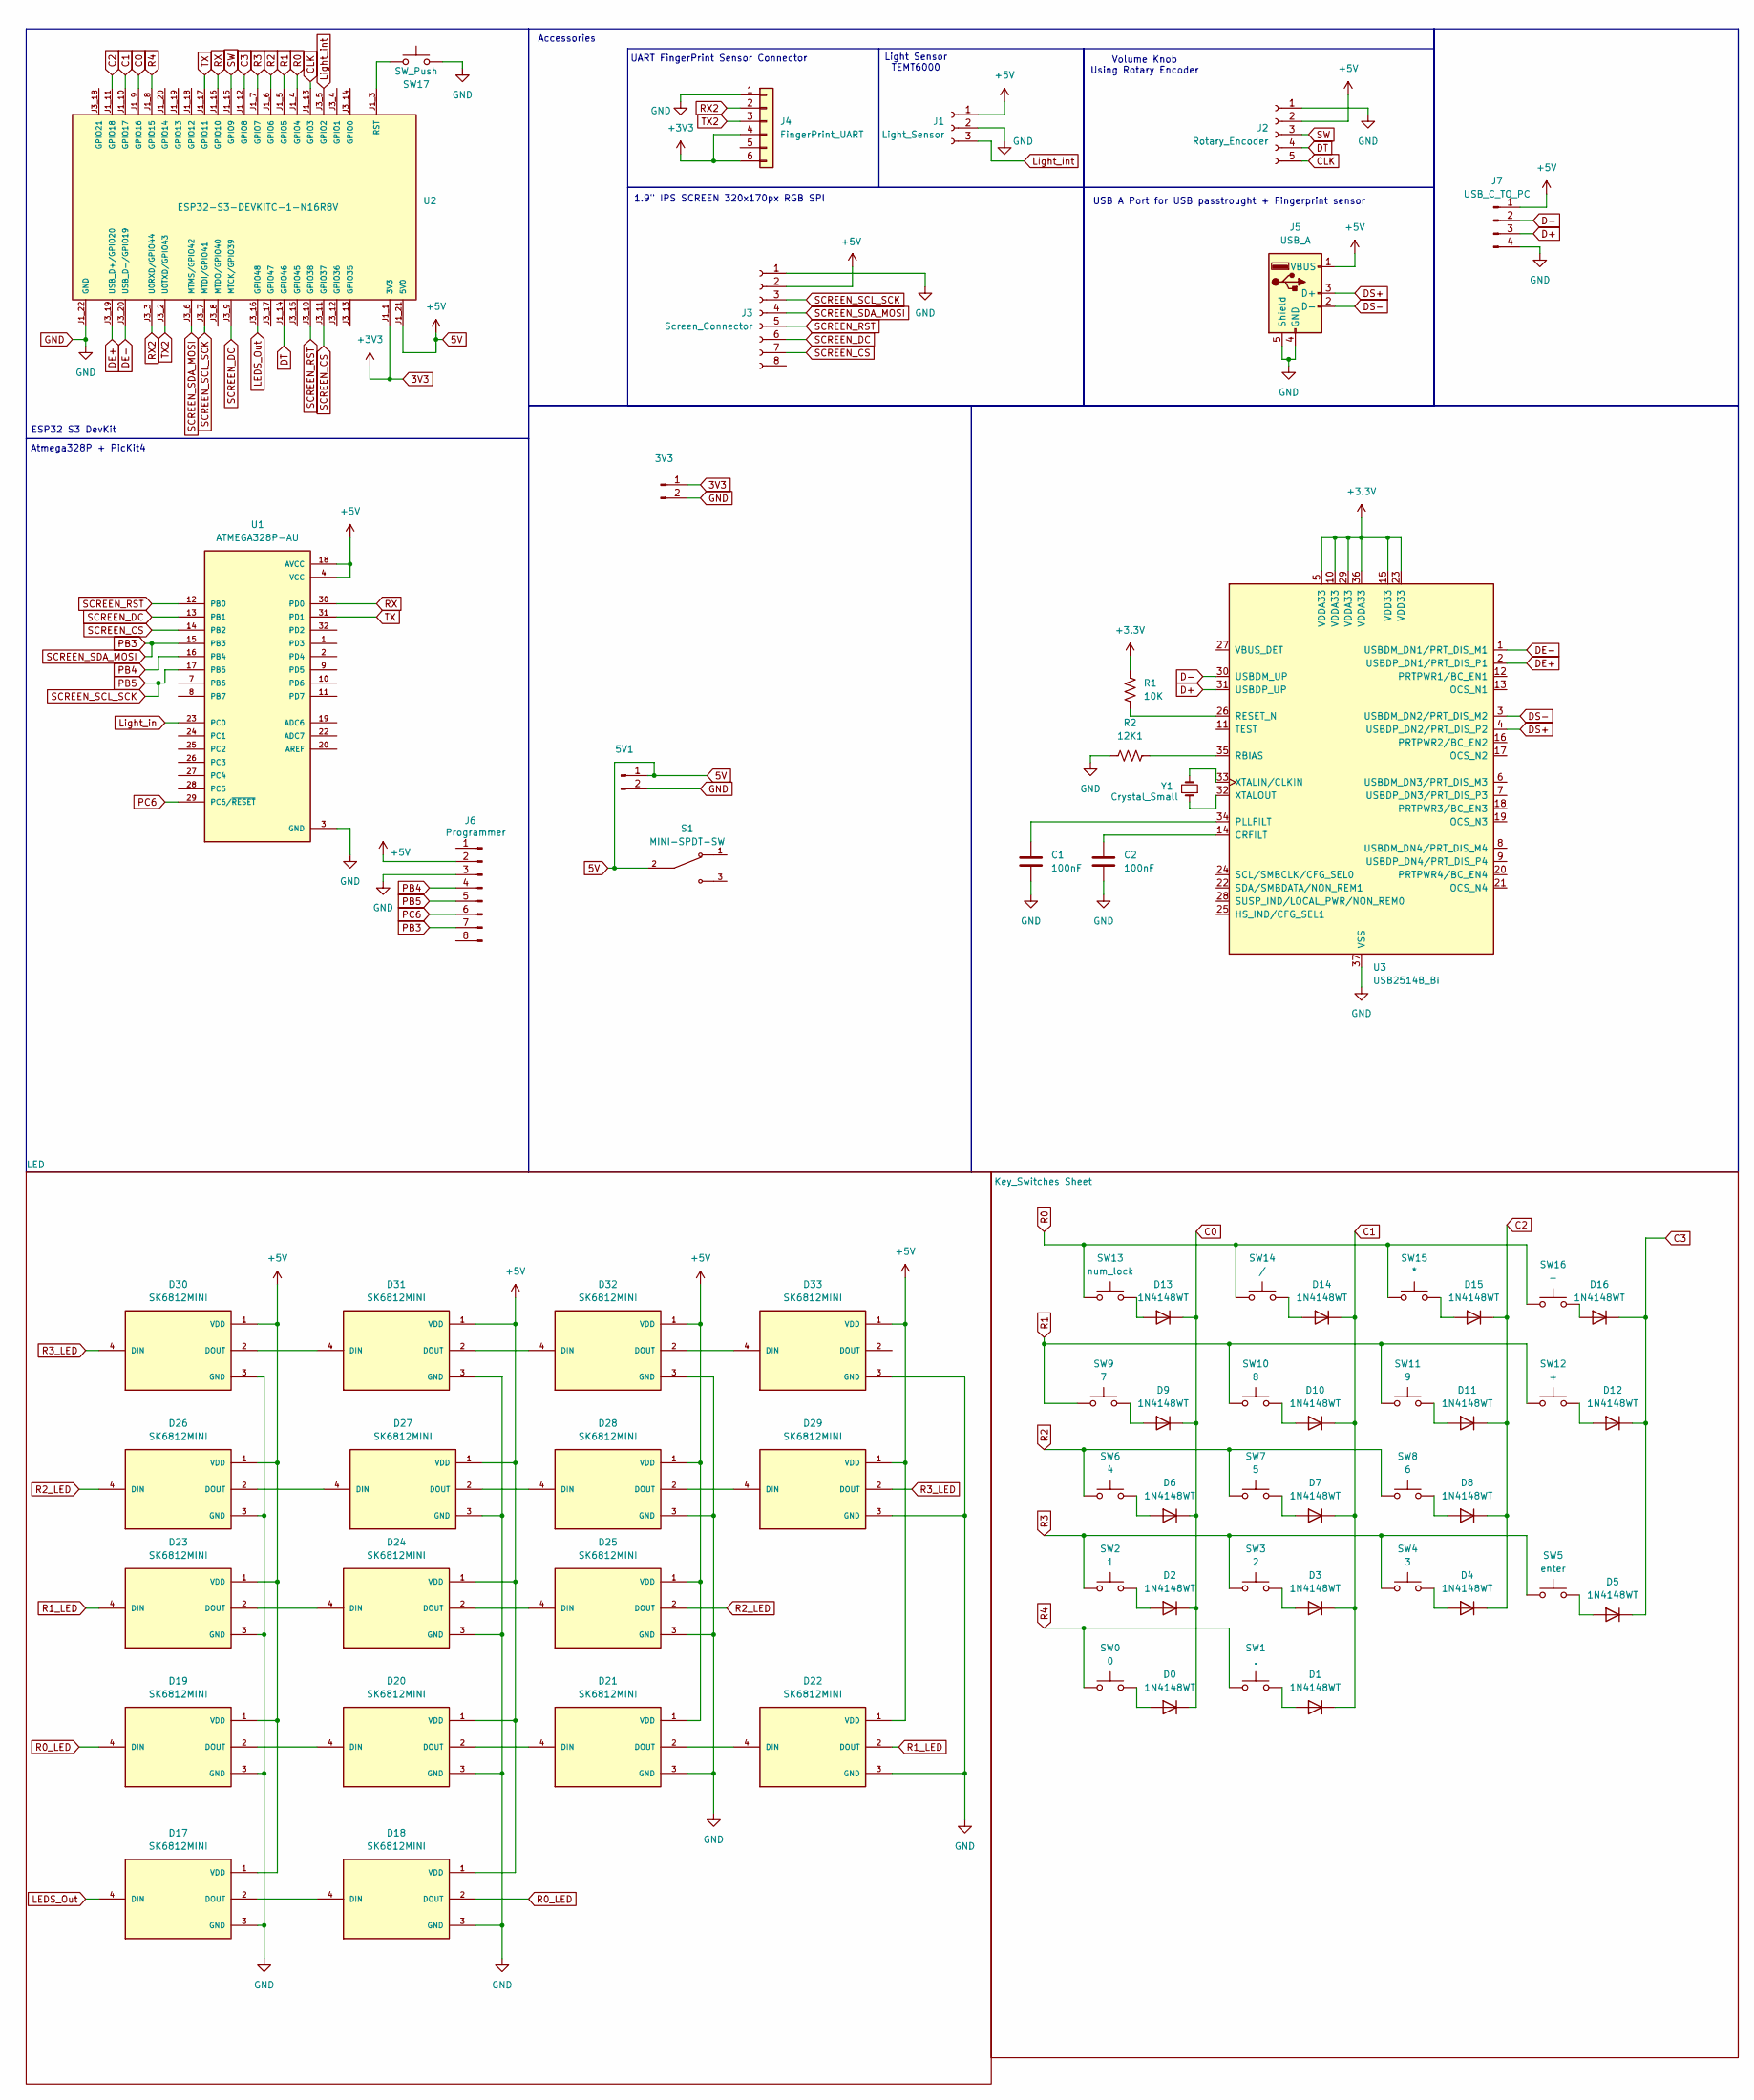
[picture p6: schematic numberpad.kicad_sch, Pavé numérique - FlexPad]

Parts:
3V3, 5V1: Conn_01x02_Pin; PinHeader_1x02_P2.54mm_Vertical
C1, C2: 100nF; C_Rect_L4.6mm_W2.0mm_P2.50mm_MKS02_FKP02
D0, D1, D2, D3, D4, D5, D6, D7, D8, D9, D10, D11, D12, D13, D14, D15, D16: 1N4148WT; Nexperia_CFP3_SOD-123W
D17, D18, D19, D20, D21, D22, D23, D24, D25, D26, D27, D28, D29, D30, D31, D32, D33: SK6812MINI; LED_SK6812-E; PARTREV 2
J1: Light_Sensor; PinHeader_1x03_P2.54mm_Vertical
J2: Rotary_Encoder; PinHeader_1x05_P2.54mm_Vertical
J3: Screen_Connector; PinHeader_1x08_P2.54mm_Vertical
J4: FingerPrint_UART; PinHeader_1x06_P2.54mm_Vertical
J5: USB_A; USB_A_Kycon_KUSBX-AS1N-B_Horizontal
J6: Programmer; PinSocket_1x08_P2.54mm_Horizontal
J7: USB_C_TO_PC; PinHeader_1x04_P2.54mm_Vertical
R1: 10K; R_Axial_DIN0204_L3.6mm_D1.6mm_P7.62mm_Horizontal
R2: 12K1; R_Axial_DIN0204_L3.6mm_D1.6mm_P7.62mm_Horizontal
S1: MINI-SPDT-SW; SW_MINI-SPDT-SW; PARTREV C
SW0: 0; SW_Gateron_LowProfile_HotSwap_PTH
SW1: .; SW_Gateron_LowProfile_HotSwap_PTH
SW2: 1; SW_Gateron_LowProfile_HotSwap_PTH
SW3: 2; SW_Gateron_LowProfile_HotSwap_PTH
SW4: 3; SW_Gateron_LowProfile_HotSwap_PTH
SW5: enter; SW_Gateron_LowProfile_HotSwap_PTH
SW6: 4; SW_Gateron_LowProfile_HotSwap_PTH
SW7: 5; SW_Gateron_LowProfile_HotSwap_PTH
SW8: 6; SW_Gateron_LowProfile_HotSwap_PTH
SW9: 7; SW_Gateron_LowProfile_HotSwap_PTH
SW10: 8; SW_Gateron_LowProfile_HotSwap_PTH
SW11: 9; SW_Gateron_LowProfile_HotSwap_PTH
SW12: +; SW_Gateron_LowProfile_HotSwap_PTH
SW13: num_lock; SW_Gateron_LowProfile_HotSwap_PTH
SW14: /; SW_Gateron_LowProfile_HotSwap_PTH
SW15: *; SW_Gateron_LowProfile_HotSwap_PTH
SW16: -; SW_Gateron_LowProfile_HotSwap_PTH
SW17: SW_Push; SW_TH_Tactile_Omron_B3F-100x
U1: ATMEGA328P-AU; QFP80P900X900X120-32N; PARTREV 8271A
U2: ESP32-S3-DEVKITC-1-N16R8V; XCVR_ESP32-S3-DEVKITC-1-N8R2; PARTREV 1.1
U3: USB2514B_Bi; SQFN36_6X6_MCH
Y1: Crystal_Small; Crystal_HC49-U_Vertical

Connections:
3V3: 3V3.1, J4.4, J4.6, U2.J1_1 (3V3), U2.J1_2 (3V3)
5V: 5V1.1, D17.1 (VDD), D18.1 (VDD), D19.1 (VDD), D20.1 (VDD), D21.1 (VDD), D22.1 (VDD), D23.1 (VDD), D24.1 (VDD), D25.1 (VDD), D26.1 (VDD), D27.1 (VDD), D28.1 (VDD), D29.1 (VDD), D30.1 (VDD), D31.1 (VDD), D32.1 (VDD), D33.1 (VDD), J1.1, J2.2, J3.2, J5.1 (VBUS), J6.2, J7.1, S1.2, U1.4 (VCC), U1.6 (VCC), U1.18 (AVCC), U2.J1_21 (5V0); also elsewhere on the board
+3.3V: R1.1, U3.5 (VDDA33), U3.10 (VDDA33), U3.15 (VDD33), U3.23 (VDD33), U3.29 (VDDA33), U3.36 (VDDA33)
C0: D0.1 (K), D2.1 (K), D6.1 (K), D9.1 (K), D13.1 (K), U2.J1_9 (GPIO16)
C1: D1.1 (K), D3.1 (K), D7.1 (K), D10.1 (K), D14.1 (K), U2.J1_10 (GPIO17)
C2: D4.1 (K), D8.1 (K), D11.1 (K), D15.1 (K), U2.J1_11 (GPIO18)
C3: D5.1 (K), D12.1 (K), D16.1 (K), U2.J1_12 (GPIO8)
CLK: J2.5, U2.J1_13 (GPIO3)
D+: J7.3, U3.31 (USBDP_UP)
D-: J7.2, U3.30 (USBDM_UP)
DE+: U2.J3_19 (USB_D+/GPIO20), U3.2 (USBDP_DN1/PRT_DIS_P1)
DE-: U2.J3_20 (USB_D-/GPIO19), U3.1 (USBDM_DN1/PRT_DIS_M1)
DS+: J5.3 (D+), U3.4 (USBDP_DN2/PRT_DIS_P2)
DS-: J5.2 (D-), U3.3 (USBDM_DN2/PRT_DIS_M2)
DT: J2.4, U2.J1_14 (GPIO46)
GND: 3V3.2, 5V1.2, C1.2, C2.2, D17.3 (GND), D18.3 (GND), D19.3 (GND), D20.3 (GND), D21.3 (GND), D22.3 (GND), D23.3 (GND), D24.3 (GND), D25.3 (GND), D26.3 (GND), D27.3 (GND), D28.3 (GND), D29.3 (GND), D30.3 (GND), D31.3 (GND), D32.3 (GND), D33.3 (GND), J1.2, J2.1, J3.1, J4.1, J5.4 (GND), J5.5 (Shield), J6.3, J7.4, R2.1, SW17.2, U1.3 (GND), U1.5 (GND), U1.21 (GND), U2.J1_22 (GND), U2.J3_1 (GND), U2.J3_21 (GND), U2.J3_22 (GND), U3.37 (VSS); also elsewhere on the board
LEDS_Out: D17.4 (DIN), U2.J3_16 (GPIO48)
Light_in: U1.23 (PC0)
Light_int: J1.3, U2.J3_5 (GPIO2); also elsewhere on the board
unnamed: D0.2 (A), SW0.2
unnamed: D1.2 (A), SW1.2
unnamed: D2.2 (A), SW2.2
unnamed: D3.2 (A), SW3.2
unnamed: D4.2 (A), SW4.2
unnamed: D5.2 (A), SW5.2
unnamed: D6.2 (A), SW6.2
unnamed: D7.2 (A), SW7.2
unnamed: D8.2 (A), SW8.2
unnamed: D9.2 (A), SW9.2
unnamed: D10.2 (A), SW10.2
unnamed: D11.2 (A), SW11.2
unnamed: D12.2 (A), SW12.2
unnamed: D13.2 (A), SW13.2
unnamed: D14.2 (A), SW14.2
unnamed: D15.2 (A), SW15.2
unnamed: D16.2 (A), SW16.2
unnamed: D17.2 (DOUT), D18.4 (DIN)
unnamed: D19.2 (DOUT), D20.4 (DIN)
unnamed: D20.2 (DOUT), D21.4 (DIN)
unnamed: D21.2 (DOUT), D22.4 (DIN)
unnamed: D23.2 (DOUT), D24.4 (DIN)
unnamed: D24.2 (DOUT), D25.4 (DIN)
unnamed: D26.2 (DOUT), D27.4 (DIN)
unnamed: D27.2 (DOUT), D28.4 (DIN)
unnamed: D28.2 (DOUT), D29.4 (DIN)
unnamed: D30.2 (DOUT), D31.4 (DIN)
unnamed: D31.2 (DOUT), D32.4 (DIN)
unnamed: D32.2 (DOUT), D33.4 (DIN)
unnamed: SW17.1, U2.J1_3 (RST)
unnamed: C2.1, U3.14 (CRFILT)
unnamed: C1.1, U3.34 (PLLFILT)
unnamed: R2.2, U3.35 (RBIAS)
unnamed: R1.2, U3.26 (RESET_N)
unnamed: U3.33 (XTALIN/CLKIN), Y1.2
unnamed: U3.32 (XTALOUT), Y1.1
PB3: J3.4, J6.7, U1.15 (PB3), U2.J3_6 (MTMS/GPIO42)
PB4: J6.4, U1.16 (PB4)
PB5: J3.3, J6.5, U1.17 (PB5), U2.J3_7 (MTDI/GPIO41)
PC6: J6.6, U1.29 (PC6/~RESET)
R0: SW13.1, SW14.1, SW15.1, SW16.1, U2.J1_4 (GPIO4)
R0_LED: D18.2 (DOUT), D19.4 (DIN)
R1: SW9.1, SW10.1, SW11.1, SW12.1, U2.J1_5 (GPIO5)
R1_LED: D22.2 (DOUT), D23.4 (DIN)
R2: SW6.1, SW7.1, SW8.1, U2.J1_6 (GPIO6)
R2_LED: D25.2 (DOUT), D26.4 (DIN)
R3: SW2.1, SW3.1, SW4.1, SW5.1, U2.J1_7 (GPIO7)
R3_LED: D29.2 (DOUT), D30.4 (DIN)
R4: SW0.1, SW1.1, U2.J1_8 (GPIO15)
RX: U1.30 (PD0), U2.J1_16 (GPIO10)
RX2: J4.2, U2.J3_3 (U0RXD/GPIO44)
SCREEN_CS: J3.7, U1.14 (PB2), U2.J3_11 (GPIO37)
SCREEN_DC: J3.6, U1.13 (PB1), U2.J3_9 (MTCK/GPIO39)
SCREEN_RST: J3.5, U1.12 (PB0), U2.J3_10 (GPIO38)
SW: J2.3, U2.J1_15 (GPIO9)
TX: U1.31 (PD1), U2.J1_17 (GPIO11)
TX2: J4.3, U2.J3_2 (U0TXD/GPIO43)

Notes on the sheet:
1.9" IPS SCREEN 320x170px RGB SPI
USB A Port for USB passtrought + Fingerprint sensor
Light Sensor TEMT6000
Volume Knob Using Rotary Encoder
Atmega328P + PicKit4
UART FingerPrint Sensor Connector
ESP32 S3 DevKit
Accessories

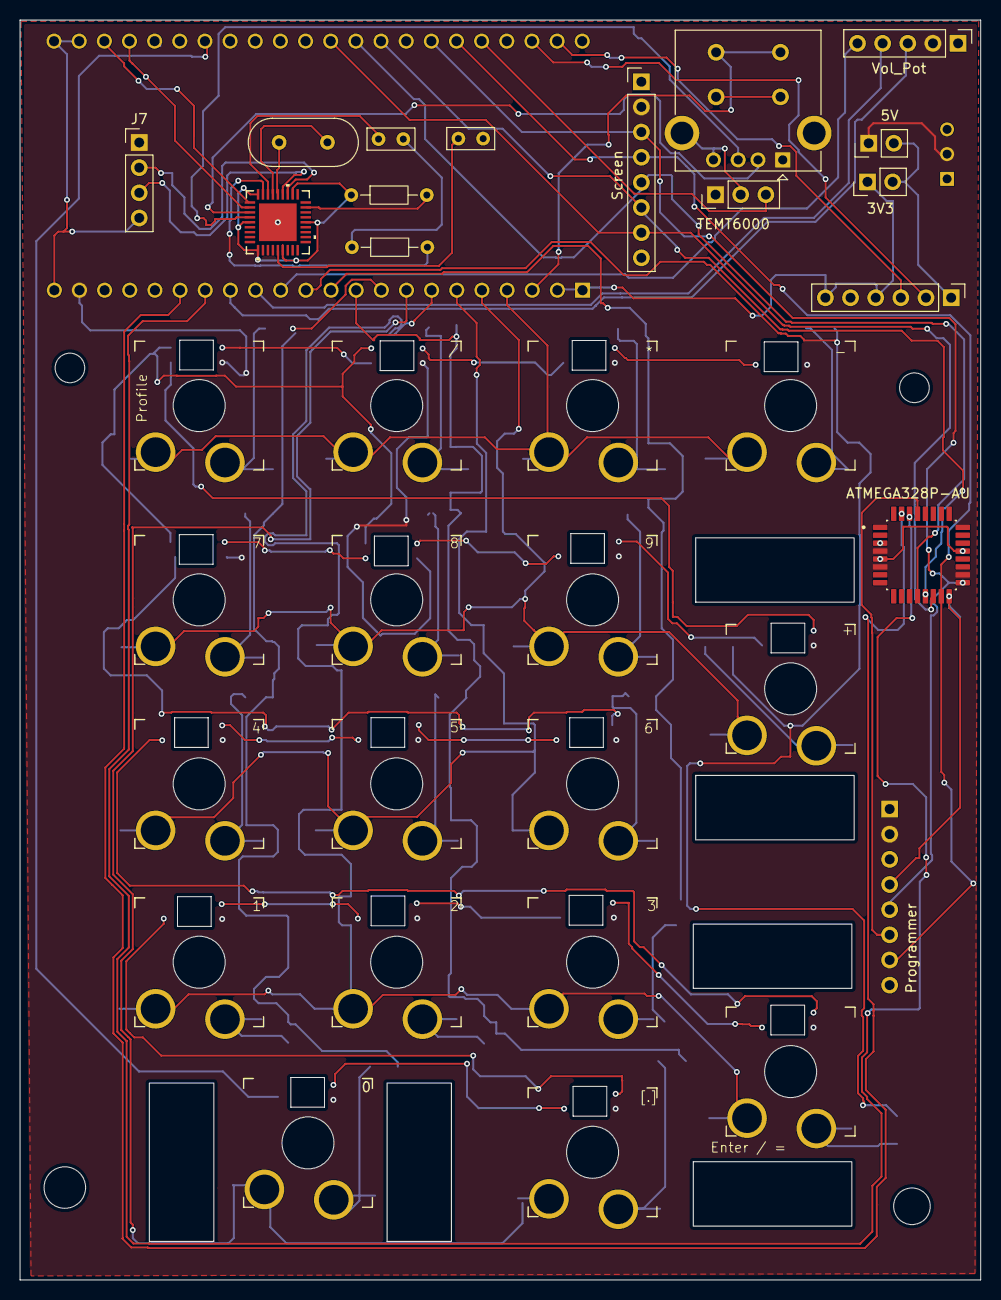
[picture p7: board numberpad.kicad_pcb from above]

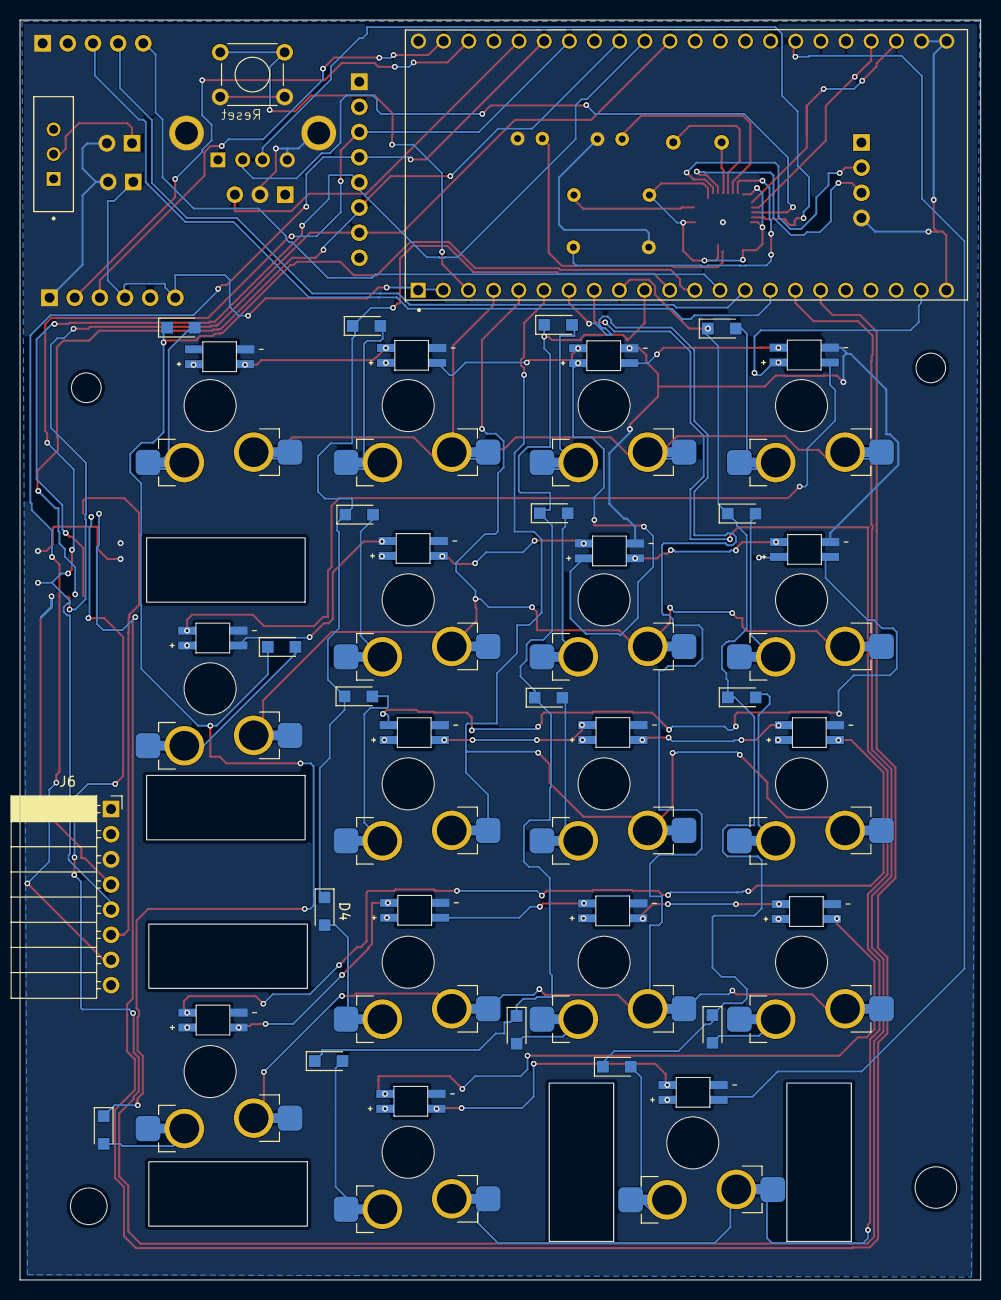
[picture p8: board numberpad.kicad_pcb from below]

Board: 2 copper layers, 97.0 x 127.2 mm, 70 parts (38 on the bottom side), 75 nets.

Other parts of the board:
TEMT6000: Light_Sensor; PinHeader_1x03_P2.54mm_Vertical

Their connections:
5V: TEMT6000.1; also elsewhere on the board
GND: TEMT6000.2; also elsewhere on the board
Light_int: TEMT6000.3; also elsewhere on the board

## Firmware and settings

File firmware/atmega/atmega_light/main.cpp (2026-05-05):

/*
 * ATmega328P Light Sensor & LED Controller with ST7789 Display
 * 
 * Fonctionnalités:
 * - Lecture du capteur TEMT6000 (luminosité ambiante)
 * - Communication UART avec ESP32 (57600 bauds @ 8 MHz, double vitesse U2X)
 * - Contrôle PWM de la LED de backlight
 * - Affichage sur écran ST7789 TFT (SPI)
 * 
 * Pins:
 * - TEMT6000: ADC0 (PC0, Pin 23)
 * - LED Backlight: OC0B (PD5, Pin 19) - PWM
 * - UART RX: PD0 (Pin 2) - Reçoit de l'ESP32
 * - UART TX: PD1 (Pin 3) - Envoie à l'ESP32
 * - ST7789 MOSI: PB3 (Pin 17) - SPI Data
 * - ST7789 SCK: PB5 (Pin 19) - SPI Clock
 * - ST7789 CS: PB2 (Pin 16) - Chip Select
 * - ST7789 DC: PB1 (Pin 15) - Data/Command
 * - ST7789 RST: PB0 (Pin 14) - Reset (optionnel, peut être connecté à VCC) 
 */ 

#include <avr/io.h>
#include <avr/interrupt.h>
#include <avr/wdt.h>
#ifndef F_CPU
#define F_CPU 8000000UL
#endif
#include <util/delay.h>
#include <avr/pgmspace.h>
#include <avr/sleep.h>
#include <string.h>

// Configuration UART — 57600 baud @ 8 MHz avec U2X (diviseur 8, erreur raisonnable)
#define UART_BAUD 57600
#define UART_UBRR ((F_CPU / (8UL * UART_BAUD)) - 1UL)

// Protocole UART
// Format: [CMD] [DATA...] [\n]
#define CMD_READ_LIGHT 0x01  // Lire la luminosité
#define CMD_SET_LED 0x02     // Définir la luminosité LED (0-255)
#define CMD_GET_LED 0x03     // Obtenir la luminosité LED actuelle
#define CMD_UPDATE_DISPLAY 0x04  // Mettre à jour l'affichage ST7789
#define CMD_SET_DISPLAY_DATA 0x05  // Envoyer les données d'affichage (profil, mode, etc.)
#define CMD_SET_DISPLAY_IMAGE 0x08  // Commencer la réception d'une image RGB565
#define CMD_SET_DISPLAY_IMAGE_CHUNK 0x09  // Recevoir un chunk d'image
#define CMD_SET_ATMEGA_DEBUG 0x0A  // Activer/désactiver le debug UART sur l'ATmega
#define CMD_SET_ATMEGA_LOG_LEVEL 0x0B  // Définir le niveau de log de l'ATmega
#define CMD_SET_LAST_KEY 0x0C  // Envoyer uniquement la dernière touche appuyée
#define CMD_PREPARE_SLEEP 0x0E // ESP32 : avant veille profonde (BL + consignes + SLPIN)
#define CMD_RESUME_FROM_SLEEP 0x0F // ESP32 : réveil rapide — SLPOUT + DISPON + rétro ( données: bl_on, bl_val )

// Capteur TEMT6000: 0 = ADC élevé = clair (LED OFF si >= 500), ADC bas = sombre (LED ON)
#define LIGHT_SENSOR_INVERTED 0

// Configuration ST7789
// Pour un écran 1.9" 170x320, utiliser 170 comme hauteur
// Si il y a du bruit en bas, essayer 172 ou ajuster les offsets
#define ST7789_WIDTH 320
// Beaucoup de modules 1.9" sont 170x320 (landscape = 320x170).
// Une hauteur trop grande peut adresser hors zone visible (aucun pixel affiché).
#define ST7789_HEIGHT 170
// Offsets matériels (très commun sur les dalles 170x320 basées ST7789)
// Si l'écran reste vide, essaie YSTART=0 ou XSTART=35 selon ton module/rotation.
#define ST7789_XSTART 0
#define ST7789_YSTART 35
#define ST7789_CS_PORT PORTB
#define ST7789_CS_DDR DDRB
#define ST7789_CS_PIN PB2
#define ST7789_DC_PORT PORTB
#define ST7789_DC_DDR DDRB
#define ST7789_DC_PIN PB1
#define ST7789_RST_PORT PORTB
#define ST7789_RST_DDR DDRB
#define ST7789_RST_PIN PB0

// Commandes ST7789
#define ST7789_NOP 0x00
#define ST7789_SWRESET 0x01
#define ST7789_SLPOUT 0x11
#define ST7789_SLPIN 0x10
#define ST7789_DISPOFF 0x28
#define ST7789_DISPON 0x29
#define ST7789_CASET 0x2A
#define ST7789_RASET 0x2B
#define ST7789_RAMWR 0x2C
#define ST7789_MADCTL 0x36
#define ST7789_COLMOD 0x3A
#define ST7789_INVON 0x21
#define ST7789_INVOFF 0x20

// Variables globales UART (SRAM ATmega328P = 2 Ko — éviter 8×256 octets de file)
#define UART_BUFFER_SIZE 128
#define UART_LINE_QUEUE_DEPTH 2
volatile uint8_t uart_buffer[UART_BUFFER_SIZE];  // Ligne copiée ici avant processUartCommand
volatile uint8_t uart_buffer_index = 0;
volatile uint8_t uart_line_queue[UART_LINE_QUEUE_DEPTH][UART_BUFFER_SIZE];
volatile uint8_t uart_line_len[UART_LINE_QUEUE_DEPTH];
volatile uint8_t uart_line_q_in = 0;
volatile uint8_t uart_line_q_out = 0;
volatile uint8_t uart_line_q_count = 0;
static uint8_t uart_rx_line[UART_BUFFER_SIZE];
static volatile uint8_t uart_rx_line_len = 0;
volatile uint8_t uart_command = 0;
volatile uint8_t led_brightness = 0;  // 0-255
volatile uint16_t light_level = 0;    // Valeur ADC du TEMT6000 (0-1023)
volatile uint8_t esp32_backlight_ticks = 0;  // Si > 0: utiliser display_backlight (priorité ESP32)

// Variables pour la réception d'images
#define IMAGE_CHUNK_SIZE 64  // Taille des chunks pour transmission UART (plus grand que I2C)
volatile uint32_t image_expected_size = 0;  // Taille totale RGB565 (320×170×2 = 108800 > uint16_t)
volatile uint32_t image_received_bytes = 0;  // Octets déjà écrits sur le TFT
volatile uint16_t image_chunk_index = 0;  // Index du chunk en cours
volatile uint8_t image_receiving = 0;  // Flag: 1 si on reçoit une image
volatile uint8_t image_chunk_buffer[IMAGE_CHUNK_SIZE];  // Buffer pour stocker temporairement un chunk
volatile uint8_t image_chunk_buffer_index = 0;
// Note: On dessine directement sur l'écran au lieu d'utiliser un buffer (trop grand pour RAM)

// Variables pour les données d'affichage
#define DISPLAY_DATA_BUFFER_SIZE 64
volatile char display_mode[16] = "data";
volatile char display_profile[32] = "Profile 1";
volatile char display_output_mode[16] = "usb";
volatile uint8_t display_keys_count = 0;
volatile uint8_t display_backlight_enabled = 0;
volatile char display_last_key[16] = "";  // Dernière touche appuyée
volatile char display_connected_device[32] = "";  // Appareil connecté (USB, Bluetooth, etc.)
volatile uint8_t display_backlight_brightness = 0;
volatile char display_custom1[32] = "";
volatile char display_custom2[32] = "";
volatile uint8_t display_brightness = 128;
volatile uint8_t display_data_receiving = 0;
volatile uint8_t display_data_buffer_index = 0;
volatile uint8_t display_initialized = 0;  // Flag: 1 si l'affichage a été initialisé avec Welcome
/** 1 si CMD SLPIN actif : tout st7789_write_cmd (sauf SLPIN) force SLPOUT + délai avant la commande. */
static uint8_t tft_panel_asleep = 0;
volatile uint8_t display_force_ui_reset = 0;  // 1 après image/gif → data : forcer redessin HUD complet

// Variables pour le debug et logging
volatile uint8_t debug_enabled = 0;  // 0 = désactivé, 1 = activé
volatile uint8_t log_level = 2;  // 0 = none, 1 = error, 2 = info, 3 = debug

// Prototype de uart_send_byte (déclaré avant debug_print pour éviter les erreurs de compilation)
void uart_send_byte(uint8_t data);

// Debug: Utiliser l'UART principal (vers ESP32) pour les messages de débogage
// Tous les messages debug_print() seront envoyés sur l'UART principal (115200 baud)
// L'ESP32 pourra les recevoir et les logger
void debug_init(void) {
    // Pas besoin d'initialiser ici, l'UART principal est déjà initialisé dans uart_init()
    // Cette fonction existe juste pour compatibilité
}

// Envoyer un string sur l'UART principal (vers ESP32)
void debug_print(const char* str) {
    while (*str) {
        uart_send_byte(*str++);
    }
}

// Envoyer une valeur hexadécimale sur l'UART principal
void debug_print_hex(uint8_t val) {
    char hex[] = "0123456789ABCDEF";
    uart_send_byte(hex[(val >> 4) & 0x0F]);
    uart_send_byte(hex[val & 0x0F]);
}

// Envoyer une valeur décimale sur l'UART principal
void debug_print_dec(uint16_t val) {
    char buf[6];
    uint8_t i = 0;
    if (val == 0) {
        uart_send_byte('0');
        return;
    }
    while (val > 0 && i < 5) {
        buf[i++] = '0' + (val % 10);
        val /= 10;
    }
    while (i > 0) {
        uart_send_byte(buf[--i]);
    }
}

void debug_print_u32(uint32_t val) {
    char buf[11];
    uint8_t i = 0;
    if (val == 0) {
        uart_send_byte('0');
        return;
    }
    while (val > 0 && i < 10) {
        buf[i++] = '0' + (uint8_t)(val % 10u);
        val /= 10u;
    }
    while (i > 0) {
        uart_send_byte(buf[--i]);
    }
}

// Macros conditionnelles pour le debug selon le niveau
#define LOG_ERROR(x) do { if (debug_enabled && log_level >= 1) debug_print(x); } while(0)
#define LOG_INFO(x) do { if (debug_enabled && log_level >= 2) debug_print(x); } while(0)
#define LOG_DEBUG(x) do { if (debug_enabled && log_level >= 3) debug_print(x); } while(0)

// Prototypes de fonctions ST7789
void st7789_write_cmd(uint8_t cmd);
void st7789_write_data(uint8_t data);
void st7789_init(void);
void st7789_set_window(uint16_t x0, uint16_t y0, uint16_t x1, uint16_t y1);
void st7789_fill_screen(uint16_t color);
void st7789_fill_rect(uint16_t x, uint16_t y, uint16_t w, uint16_t h, uint16_t color);
void st7789_draw_image_rgb565(uint8_t* imageData, uint16_t imageSize);
void st7789_update_display(void);
void st7789_draw_char(uint16_t x, uint16_t y, char c, uint16_t color, uint16_t bg_color);
void st7789_draw_text(uint16_t x, uint16_t y, const char* text, uint16_t color, uint16_t bg_color);
void processUartCommand(void);
void uart_send_response(uint8_t cmd, uint8_t* data, uint8_t len);
void uart_send_light_ascii(void);
void display_light_level_on_screen(uint16_t value);
void display_simple_info(void);
void display_init_panel(void);
void display_update_partial(uint8_t force_key_device);
void display_draw_image_footer(void);

// Initialiser ADC pour TEMT6000
void adc_init(void) {
    // ADC0 (PC0) comme entrée analogique
    ADMUX = (1 << REFS0);  // Référence AVCC (5V)
    ADCSRA = (1 << ADEN) | (1 << ADPS2) | (1 << ADPS1) | (1 << ADPS0);  // Prescaler 128
}

// Lire la valeur ADC du TEMT6000
uint16_t adc_read(void) {
    ADCSRA |= (1 << ADSC);  // Démarrer conversion
    while (ADCSRA & (1 << ADSC));  // Attendre fin conversion
    return ADC;
}

// Initialiser PWM pour LED (Timer0, OC0B sur PD5)
void pwm_init(void) {
    // Mode PWM Phase Correct, Top = 0xFF
    TCCR0A = (1 << WGM00) | (1 << COM0B1);  // PWM Phase Correct, OC0B non-inversé
    TCCR0B = (1 << CS00);  // Prescaler 1 (pas de division)
    
    // PD5 (OC0B) comme sortie
    DDRD |= (1 << PD5);
    
    OCR0B = 0;  // LED éteinte par défaut
}

// Définir la luminosité LED (0-255)
void set_led_brightness(uint8_t brightness) {
    led_brightness = brightness;
    OCR0B = brightness;  // PWM duty cycle
}

/** Coupe le backlight et invalide la priorité ESP32 — veille panneau (SLPIN / IDLE). */
static void backlight_shutdown_for_panel_sleep(void) {
    display_backlight_enabled = 0;
    display_backlight_brightness = 0;
    esp32_backlight_ticks = 0;
    set_led_brightness(0);
}

/**
 * PWM TFT : ON seulement si la dalle n’est pas en SLPIN.
 * Sinon l’ESP32 (send_display_data / last_key) rallumerait la LED en boucle pendant la veille.
 */
static void apply_display_backlight_from_esp32_consider_sleep(void) {
    if (tft_panel_asleep) {
        esp32_backlight_ticks = 0;
        set_led_brightness(0);
    } else {
        esp32_backlight_ticks = 100;
        set_led_brightness(display_backlight_enabled ? display_backlight_brightness : 0);
    }
}

// Initialiser SPI pour ST7789
void spi_init(void) {
    // IMPORTANT (AVR): le pin SS (PB2) DOIT être configuré en sortie et maintenu HIGH
    // avant d'activer le SPI en mode maître, sinon le matériel peut basculer en mode esclave
    // et certaines transmissions peuvent bloquer (SPIF ne se déclenche pas).
    ST7789_CS_DDR |= (1 << ST7789_CS_PIN);
    ST7789_CS_PORT |= (1 << ST7789_CS_PIN);  // CS HIGH (SS high)

    // Pins de contrôle ST7789
    ST7789_DC_DDR |= (1 << ST7789_DC_PIN);
    ST7789_RST_DDR |= (1 << ST7789_RST_PIN);
    ST7789_RST_PORT |= (1 << ST7789_RST_PIN); // RST HIGH par défaut

    // Pins SPI
    DDRB |= (1 << PB3) | (1 << PB5);  // MOSI et SCK en sortie
    DDRB &= ~(1 << PB4);              // MISO en entrée

    // Configurer SPI en mode maître, vitesse F_CPU/2
    SPCR = (1 << SPE) | (1 << MSTR);  // SPI Enable, Master mode
    SPSR = (1 << SPI2X);              // Double speed
}

// Envoyer un byte via SPI
void spi_write(uint8_t data) {
    SPDR = data;
    while (!(SPSR & (1 << SPIF)));
}

// Envoyer une commande au ST7789 (réveille le panneau si en SLPIN, sauf pour la commande SLPIN elle-même)
void st7789_write_cmd(uint8_t cmd) {
    if (cmd == ST7789_SLPIN) {
        backlight_shutdown_for_panel_sleep();
        ST7789_CS_PORT &= ~(1 << ST7789_CS_PIN);
        ST7789_DC_PORT &= ~(1 << ST7789_DC_PIN);
        spi_write(cmd);
        ST7789_CS_PORT |= (1 << ST7789_CS_PIN);
        tft_panel_asleep = 1;
        return;
    }
    if (tft_panel_asleep) {
        ST7789_CS_PORT &= ~(1 << ST7789_CS_PIN);
        ST7789_DC_PORT &= ~(1 << ST7789_DC_PIN);
        spi_write(ST7789_SLPOUT);
        ST7789_CS_PORT |= (1 << ST7789_CS_PIN);
        _delay_ms(120);
        tft_panel_asleep = 0;
    }
    ST7789_CS_PORT &= ~(1 << ST7789_CS_PIN);  // CS LOW
    ST7789_DC_PORT &= ~(1 << ST7789_DC_PIN);  // DC LOW (command)
    spi_write(cmd);
    ST7789_CS_PORT |= (1 << ST7789_CS_PIN);   // CS HIGH
}

// Envoyer des données au ST7789
void st7789_write_data(uint8_t data) {
    ST7789_CS_PORT &= ~(1 << ST7789_CS_PIN);  // CS LOW
    ST7789_DC_PORT |= (1 << ST7789_DC_PIN);    // DC HIGH (data)
    spi_write(data);
    ST7789_CS_PORT |= (1 << ST7789_CS_PIN);   // CS HIGH
}

// Envoyer plusieurs bytes de données
void st7789_write_data_multiple(uint8_t* data, uint16_t len) {
    ST7789_CS_PORT &= ~(1 << ST7789_CS_PIN);  // CS LOW
    ST7789_DC_PORT |= (1 << ST7789_DC_PIN);    // DC HIGH (data)
    for (uint16_t i = 0; i < len; i++) {
        spi_write(data[i]);
    }
    ST7789_CS_PORT |= (1 << ST7789_CS_PIN);   // CS HIGH
}
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
int main(void) {
    // CRITIQUE: Désactiver le watchdog timer au démarrage (si activé)
    // Le watchdog peut causer des resets si non désactivé
    MCUSR &= ~(1 << WDRF);  // Clear watchdog reset flag
    wdt_disable();  // Désactiver le watchdog
    
    // Délai initial pour stabilisation de l'alimentation
    _delay_ms(200);  // Délai plus long pour stabilisation au boot
    
    // IMPORTANT: Initialiser l'UART EN PREMIER pour que debug_print() fonctionne
    uart_init();
    _delay_ms(100);  // Attendre que l'UART soit stable
    
    // Initialiser le débogage (utilise maintenant l'UART principal)
    debug_init();
    debug_print("\r\n=== ATmega328P Light Controller ===\r\n");
    debug_print("UART Baud: 57600 (U2X)\r\n");
    debug_print("Boot sequence started...\r\n");
    
    // Initialiser les périphériques
    adc_init();
    debug_print("ADC initialized\r\n");
    
    pwm_init();
    debug_print("PWM initialized\r\n");
    // LED backlight: contrôlée par light_level (>= 500 = ON)
    
    spi_init();
    debug_print("SPI initialized\r\n");
    
    // Délai avant initialisation de l'écran pour s'assurer que l'alimentation est stable
    _delay_ms(100);
    st7789_init();
    debug_print("ST7789 initialized\r\n");
    
    // Initialiser les valeurs d'affichage par défaut
    strcpy((char*)display_mode, "data");
    strcpy((char*)display_profile, "Profile 1");
    // Par défaut, l'ESP32 utilise le HID BLE (pas USB), donc on affiche BLUETOOTH
    strcpy((char*)display_output_mode, "bluetooth");
    display_keys_count = 0;
    display_backlight_enabled = 1;
    display_backlight_brightness = 255;
    display_brightness = 128;
    
    // Ne pas appeler st7789_update_display() ici - l'affichage Welcome est déjà fait dans st7789_init()
    // On attendra qu'une commande UART demande explicitement une mise à jour
    
    debug_print("UART initialized\r\n");
    
    // Activer interruptions globales
    sei();
    debug_print("Interrupts enabled\r\n");
    debug_print("Ready!\r\n");
    
    // Boucle principale - optimisée pour la réactivité
    while (1) {
        // Traiter toutes les lignes UART mises en file par l'ISR (évite perte entre paquets image)
        for (;;) {
            uint8_t cnt;
            cli();
            cnt = uart_line_q_count;
            sei();
            if (cnt == 0) {
                break;
            }
            cli();
            uint8_t out = uart_line_q_out;
            uint8_t len = uart_line_len[out];
            uart_line_q_out = (uint8_t)((uart_line_q_out + 1u) % UART_LINE_QUEUE_DEPTH);
            uart_line_q_count--;
            sei();
            if (len == 0 || len >= UART_BUFFER_SIZE) {
                continue;
            }
            memcpy((void*)uart_buffer, (const void*)uart_line_queue[out], len);
            uart_buffer_index = len;
            processUartCommand();
        }
        
        // Économie : dalle en SLPIN → pas d’ADC/UI périodiques, MCU en veille IDLE (UART RX réveille).
        if (!tft_panel_asleep) {
            // Lire la luminosité toutes les ~20ms (au lieu de 100ms)
            static uint8_t adc_counter = 0;
            adc_counter++;
            if (adc_counter >= 5) {  // ~100ms (5 * 20ms) pour l'ADC
                adc_counter = 0;
                light_level = adc_read();
                if (esp32_backlight_ticks > 0) {
                    esp32_backlight_ticks--;
                }
                set_led_brightness(display_backlight_enabled ? display_backlight_brightness : 0);
            }

            static uint16_t ui_counter = 0;
            static uint16_t last_shown_light_ui = 0xFFFF;
            ui_counter++;
            if (ui_counter >= 10) {
                ui_counter = 0;
                uint16_t diff;
                if (light_level > last_shown_light_ui) {
                    diff = light_level - last_shown_light_ui;
                } else {
                    diff = last_shown_light_ui - light_level;
                }
                if (diff >= 5 || last_shown_light_ui == 0xFFFF) {
                    display_simple_info();
                    last_shown_light_ui = light_level;
                }
            }

            static uint16_t debug_counter = 0;
            debug_counter++;
            if (debug_counter >= 250) {
                debug_counter = 0;
                debug_print("[LIGHT] Level: ");
                debug_print_dec(light_level);
                debug_print(" (0x");
                debug_print_hex((uint8_t)(light_level >> 8));
                debug_print_hex((uint8_t)(light_level & 0xFF));
                debug_print(")\r\n");
            }

            _delay_ms(20);
        } else {
            uint8_t qcnt;
            cli();
            qcnt = uart_line_q_count;
            sei();
            if (qcnt == 0) {
                /* Dalle en veille : garantir PWM backlight à 0 (boucle IDLE sans passage ADC). */
                set_led_brightness(0);
                set_sleep_mode(SLEEP_MODE_IDLE);
                sleep_enable();
                sei();
                sleep_cpu();
                sleep_disable();
            } else {
                _delay_ms(1);
            }
        }
    }
    
    return 0;
}

// Envoyer la luminosité actuelle en ASCII lisible sur l'UART (ex: "LIGHT=512\n")
void uart_send_light_ascii(void) {
    uint16_t value = light_level;
    
    // Prefixe
    uart_send_byte('L');
    uart_send_byte('I');
    uart_send_byte('G');
    uart_send_byte('H');
    uart_send_byte('T');
    uart_send_byte('=');
    
    // Conversion décimale (similaire à debug_print_dec mais sur l'UART principal)
    char buf[6];
    uint8_t i = 0;
    if (value == 0) {
        uart_send_byte('0');
    } else {
        while (value > 0 && i < 5) {
            buf[i++] = '0' + (value % 10);
            value /= 10;
        }
        while (i > 0) {
            uart_send_byte(buf[--i]);
        }
    }
    uart_send_byte('\n');
}

    // Afficher la valeur de luminosité sur l'écran ST7789
void display_light_level_on_screen(uint16_t value) {
    // Construire une chaîne "LIGHT: 0123"
    char text[16];
    text[0] = 'L';
    text[1] = 'I';
    text[2] = 'G';
    text[3] = 'H';
    text[4] = 'T';
    text[5] = ':';
    text[6] = ' ';
    
    // Conversion décimale dans text[7..]
    char buf[6];
    uint8_t i = 0;
    uint16_t v = value;
    if (v == 0) {
        text[7] = '0';
        text[8] = '\0';
    } else {
        while (v > 0 && i < 5) {
            buf[i++] = '0' + (v % 10);
            v /= 10;
        }
        uint8_t pos = 7;
        while (i > 0 && pos < sizeof(text) - 1) {
            text[pos++] = buf[--i];
        }
        text[pos] = '\0';
    }
    
    // Couleurs simples
    uint16_t black = 0x0000;
    uint16_t fg_gray = 0x8430;  // Même neutre que UI_TEXT_HI
    
    // Afficher la luminosité juste sous la ligne "CONNECTION : ..."
    // text_y = 40, conn_y = text_y + 12 = 52 → LIGHT vers ~64
    uint16_t x = 20;
    uint16_t y = 150;
    uint16_t w = 300;  // Largeur limitée pour le texte (pas toute la largeur)
    uint16_t h = 100;
    
    // Effacer uniquement la zone du texte (pas toute la largeur)
    st7789_fill_rect(x, y, w, h, black);
    
    st7789_draw_text(x, y, text, fg_gray, black);
    
    // S'assurer que le reste de l'écran en bas est noir (protection contre le bruit)
    // Effacer de y+h jusqu'en bas de l'écran
    if (y + h < ST7789_HEIGHT) {
        uint16_t clear_y = y + h;
        uint16_t clear_h = ST7789_HEIGHT - clear_y;
        st7789_fill_rect(0, clear_y, ST7789_WIDTH, clear_h, black);
    }
}

/* ─── UI : style sombre + accents or / USB vert ─── */
#define UI_BG           0x0000
#define UI_TEXT_HI      0xFFFF  // valeurs en blanc
#define UI_TEXT_DIM     0xFEC0  // libellés type « or »
#define UI_ACCENT       0xFD20  // barres / % ambiant
#define UI_DIVIDER      0xBD20  // séparateur plus visible sur fond noir
#define UI_VAL_USB      0x07F0
#define UI_VAL_BLE      0x4DDF
#define UI_VAL_IDLE     0xBDF7

#define UI_CONTENT_Y    38
#define UI_ROW_GAP      12
#define UI_ROW_LRG      18
#define UI_ROW_AMB      16
#define UI_LBL_X        10
#define UI_VAL_X        118
#define UI_GUTTER_X     6
#define UI_BAR_X        10
#define UI_BAR_W        300
#define UI_KEYS_CAP     17

/* Bande réservée en bas quand une image plein écran est affichée (alignée avec ESP map_packed565). */
#define UI_IMAGE_FOOTER_Y0  76
#define UI_FOOTER_ROW_H     10

static void ui_hrule(uint16_t y) {
    if (y >= ST7789_HEIGHT) return;
    st7789_fill_rect(8, y, ST7789_WIDTH - 16, 1, UI_DIVIDER);
}
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

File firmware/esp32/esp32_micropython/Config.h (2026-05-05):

/*
 * Config.h — Configuration centralisée du Macropad ESP32-S3
 * Inspiré de MacroPad (aayushchouhan24) — logique modulaire, HID standalone
 *
 * Le device fonctionne sur n'importe quel appareil (phone, PC) sans app.
 * Configurable via interface web (Web Serial / Web Bluetooth).
 */
#ifndef CONFIG_H
#define CONFIG_H

#include <Arduino.h>

// ─── Version ─────────────────────────────────────────────────────────────────
#define FW_VERSION_MAJOR 1
#define FW_VERSION_MINOR 0
#define FW_VERSION_PATCH 0

// ─── Matrice de touches 5×4 ─────────────────────────────────────────────────
#define NUM_ROWS 5
#define NUM_COLS 4
#define NUM_KEYS (NUM_ROWS * NUM_COLS)
// Touche réservée au changement de profil (non mappable via Web) — coin haut-gauche 0,0.
#define PROFILE_KEY_ROW 0
#define PROFILE_KEY_COL 0

static const uint8_t ROW_PINS[NUM_ROWS] = {4, 5, 6, 7, 15};   // R0..R4
static const uint8_t COL_PINS[NUM_COLS] = {16, 17, 18, 8};    // C0..C3

#define DEBOUNCE_MS 25
#define REPEAT_DELAY_MS 500
#define REPEAT_INTERVAL_MS 50

// ─── Veille profonde + réveil par touche (toute touche = n'importe quelle colonne) ─
// Avant veille : toutes les colonnes en sortie LOW, lignes en pull-up → une touche
// relie ligne/colonne → ligne à 0 → EXT1 réveil (ESP32-S3).
#define ENABLE_KEYPAD_SLEEP_WAKE     1
// Temps sans activité (touche / encodeur) avant entrée en veille (ms).
#define KEY_IDLE_DEEP_SLEEP_MS       (1u * 60u * 1000u)  // 1 min — ajuster au besoin
// GPIO pour oscilloscope : HIGH dès le début du réveil / boot jusqu'à fin de setup();
// courte impulsion HIGH à l'entrée en veille. Conflit si USE_ESP32_DISPLAY_ST7789 et RST=21.
#define SLEEP_TIMING_GPIO            21
// 0 = ne pas entrer en veille si BLE connecté (recommandé pour garder la liaison).
#define SLEEP_WHEN_BLE_CONNECTED     0
// Réveil EXT1 sans touche stable : 0 = repartir **toujours** en veille (pas de boot fantôme).
// >0 = après ce nombre de réveils « fantômes » d’affilée, boot complet (debug / matrice défaillante).
#define SLEEP_EXT1_PHANTOM_MAX_BOOT_AFTER 0
// 1 = logs détaillés (GPIO EXT1 + phrases à chaque retour veille « pré-boot »). 0 = silencieux si pas encore fini setup().
#define SLEEP_EXT1_VERBOSE_SERIAL       0

// ─── Encodeur rotatif ───────────────────────────────────────────────────────
#define ENC_CLK_PIN 3
#define ENC_DT_PIN 46
#define ENC_SW_PIN 9

#define ENC_VOLUME_COOLDOWN_MS 40   // 1 commande volume par cran, min 40ms entre chaque
#define BLE_VOLUME_STEP_DELAY_MS 130  // Android: espacement min entre rapports Consumer (évite "max ou rien")
#define ENABLE_ENCODER_VOLUME 1    // 1 = activé. Lecture avant scan matrice pour éviter interférences.

// ─── USB Passthrough (obsolète avec hub USB) ───────────────────────────────────
#define ENABLE_USB_PASSTHROUGH 0   // Hub USB = clavier + fingerprint simultanés

// ─── BLE Switch appareil (PROFILE+1 maintenu 2s) ──────────────────────────────
#define ENABLE_BLE_DEVICE_SWITCH 1
#define BLE_SWITCH_COMBO_MS 2000

// ─── UART ATmega ────────────────────────────────────────────────────────────
// Câblage: ESP32 TX(10) -> 2k2 -> ATmega RX(PD0)  |  ATmega TX(PD1) -> diviseur 2k2/3k3 -> ESP32 RX(11)
// IMPORTANT: L'ATmega en 5V envoie 5V sur PD1. L'ESP32 n'est PAS 5V tolerant!
// Diviseur requis: PD1 -> 2k2 -> [jonction vers ESP32 RX] -> 3k3 -> GND  (≈3V)
// GPIO 43/44 = terminal USB (ne pas utiliser pour ATmega)
#define ENABLE_ATMEGA_UART 1
#define ATMEGA_UART_TX 10
#define ATMEGA_UART_RX 11
// Doit correspondre au débit programmé dans firmware/atmega/atmega_light/main.cpp (57600 @ 8 MHz, U2X).
#define ATMEGA_UART_BAUD 57600

#define CMD_READ_LIGHT 0x01
#define CMD_SET_LED 0x02
#define CMD_GET_LED 0x03
#define CMD_UPDATE_DISPLAY 0x04
#define CMD_SET_DISPLAY_DATA 0x05
#define CMD_SET_DISPLAY_IMAGE 0x08
#define CMD_SET_DISPLAY_IMAGE_CHUNK 0x09
#define CMD_SET_ATMEGA_DEBUG 0x0A
#define CMD_SET_ATMEGA_LOG_LEVEL 0x0B
#define CMD_SET_LAST_KEY 0x0C
#define CMD_SET_SCREEN_MODE 0x0D  // ESP32 -> ATmega: 0=UI data, 1=QR image (runtime)
#define CMD_PREPARE_SLEEP 0x0E   // ESP32 -> ATmega: avant veille profonde (BL off + TFT SLPIN)
#define CMD_RESUME_FROM_SLEEP 0x0F // ESP32 -> ATmega: SLPOUT + DISPON + rétro (payload: [bl_on][bl_0..255])
// IMPORTANT: utiliser des valeurs hors ASCII (évite faux positifs dans les logs \r\n)
#define CMD_SHOW_QR 0xF1   // ATmega -> ESP32: demander l'affichage du QR (image)
#define CMD_IMAGE_ACK 0xF2 // ATmega -> ESP32: ACK d'un chunk image (idx low/high)
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

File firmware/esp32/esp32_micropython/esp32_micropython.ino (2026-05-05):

#include "Config.h"
#include "KeyMatrix.h"
#include "Encoder.h"
#include "HidOutput.h"

#include <USB.h>
#include <USBHIDKeyboard.h>
#include <USBHIDConsumerControl.h>
#include <BLEDevice.h>
#include <BLEServer.h>
#include <BLEUtils.h>
#include <BLE2902.h>
#include <Preferences.h>
#include <ArduinoJson.h>
#include <HardwareSerial.h>
#include <Adafruit_NeoPixel.h>
#include <Update.h>
#include <string.h>
#include <string>
#include <math.h>
#include <stdarg.h>
#if ENABLE_KEYPAD_SLEEP_WAKE
#include <esp_sleep.h>
#endif

#if USE_ESP32_DISPLAY_ST7789
#include <SPI.h>
#include <Adafruit_GFX.h>
#include <Adafruit_ST7789.h>
#endif

extern Preferences preferences;

// ==================== LOGGING HELPERS ====================
static void log_line(const char* tag, const char* fmt, ...) {
    char msg[192];
    va_list ap;
    va_start(ap, fmt);
    vsnprintf(msg, sizeof(msg), fmt, ap);
    va_end(ap);
    Serial.printf("[%-5s] %s\n", tag, msg);
}

static bool debug_web_enabled() {
    return preferences.getBool("dbg_web", false);
}

// Boot box (encadré) — pour un log "propre" et lisible.
static const int BOOT_BOX_W = 66; // largeur totale (incluant bordures)
static void boot_box_hr() {
    Serial.print("+");
    for (int i = 0; i < BOOT_BOX_W - 2; i++) Serial.print("-");
    Serial.println("+");
}
static void boot_box_line(const char* s) {
    // Contenu max = W - 4 (bordures + espaces)
    const int inner = BOOT_BOX_W - 4;
    char buf[256];
    snprintf(buf, sizeof(buf), "%.*s", inner, s ? s : "");
    int len = (int)strlen(buf);
    Serial.print("| ");
    Serial.print(buf);
    for (int i = len; i < inner; i++) Serial.print(" ");
    Serial.println(" |");
}
static void boot_box_kv(const char* k, const char* v) {
    char line[256];
    snprintf(line, sizeof(line), "%s: %s", k ? k : "", v ? v : "");
    boot_box_line(line);
}

// Base64 decode minimal (évite dépendance mbedtls)
static int base64_decode(const char* in, size_t inlen, uint8_t* out, size_t outmax, size_t* outlen) {
    static const int T[256] = {
        -1,-1,-1,-1,-1,-1,-1,-1,-1,-1,-1,-1,-1,-1,-1,-1,-1,-1,-1,-1,-1,-1,-1,-1,-1,-1,-1,-1,-1,-1,-1,-1,
        -1,-1,-1,-1,-1,-1,-1,-1,-1,-1,-1,62,-1,-1,-1,63,52,53,54,55,56,57,58,59,60,61,-1,-1,-1,-2,-1,-1,
        -1,0,1,2,3,4,5,6,7,8,9,10,11,12,13,14,15,16,17,18,19,20,21,22,23,24,25,-1,-1,-1,-1,-1,
        -1,26,27,28,29,30,31,32,33,34,35,36,37,38,39,40,41,42,43,44,45,46,47,48,49,50,51,-1,-1,-1,-1,-1
    };
    size_t o = 0;
    uint32_t v = 0;
    int n = 0;
    for (size_t i = 0; i < inlen; i++) {
        int c = T[(unsigned char)in[i]];
        if (c == -1) continue;
        if (c == -2) break;  // padding
        v = (v << 6) | (c & 0x3F);
        n++;
        if (n == 4) {
            if (o + 3 > outmax) return -1;
            out[o++] = (v >> 16) & 0xFF;
            out[o++] = (v >> 8) & 0xFF;
            out[o++] = v & 0xFF;
            n = 0;
        }
    }
    if (n == 2) { if (o + 1 > outmax) return -1; out[o++] = (v >> 4) & 0xFF; }
    else if (n == 3) { if (o + 2 > outmax) return -1; out[o++] = (v >> 10) & 0xFF; out[o++] = (v >> 2) & 0xFF; }
    *outlen = o;
    return 0;
}

// ─── Instances globales (logique modulaire) ───────────────────────────────────
KeyMatrix keyMatrix;
Encoder encoder;
HidOutput hidOutput;

HardwareSerial SerialAtmega(1);
#if ENABLE_ATMEGA_UART
// Démarré tôt dans setup() si veille matrice : permet CMD_PREPARE_SLEEP avant fin d’init.
static bool g_atmega_uart_started = false;
#endif
USBHIDKeyboard Keyboard;
USBHIDConsumerControl ConsumerControl;
Preferences preferences;

// Keymap par défaut (grille physique)
const char* DEFAULT_KEYMAP[NUM_ROWS][NUM_COLS] = {
    {"PROFILE", "/", "*", "-"},
    {"7", "8", "9", "+"},
    {"4", "5", "6", ""},
    {"1", "2", "3", "="},
    {"0", ".", "", ""}
};

String KEYMAP[NUM_ROWS][NUM_COLS];

// Profils (côté firmware) — 3 profils cyclables via touche PROFILE (0,0)
static const uint8_t PROFILE_COUNT_DEFAULT = 3;
uint8_t profileCount = PROFILE_COUNT_DEFAULT;
uint8_t activeProfileIndex = 0;  // 0 = Profil 1

// Forward declarations nécessaires pour les helpers de profils
void apply_keymap_defaults();
void send_display_data_to_atmega();
void send_config_to_web();
void send_status_message(String message);

static String profileName(uint8_t idx) {
    return "Profil " + String((int)idx + 1);
}

static String getStoredProfileName(uint8_t idx) {
    String k = "profile_name_" + String((int)idx);
    String name = preferences.getString(k.c_str(), "");
    if (name.length() == 0) return profileName(idx);
    return name;
}

static void storeProfileName(uint8_t idx, const String& name) {
    String k = "profile_name_" + String((int)idx);
    preferences.putString(k.c_str(), name);
}
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

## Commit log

2026-02-03 pcb update
    [numberpad.kicad_pcb, numberpad.kicad_sch]
2026-02-10 update screen support now display information for the screen + brightness.
    [numberpad.kicad_sch]
2026-02-24 Windows support !
    Windows HID support have been added in this version also working with Android. Both only work with default keymap.
    [LED.kicad_sch, Switch.kicad_sch, numberpad.kicad_pcb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]
2026-02-24 update to support volume on android + update screen. missing device connected name + last key pressed
    [numberpad.kicad_pcb, numberpad.kicad_sch]
2026-02-25 ajout de system de backlight+ touche+com uart + last key
    [numberpad.kicad_sch]
2026-02-28 OTA intergration
    [numberpad.kicad_pcb]
2026-04-27 v.1.1
    PCB Key spacing, style refresh, web ui bug fix, qol feature implimentation (cart item ajust, remove from cart)
    [numberpad-B_Adhesive.gbr, numberpad-B_Courtyard.gbr, numberpad-B_Cu.gbr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]
2026-04-28 screen fix
    [.step, numberpad.kicad_pcb, numberpad1.step]
2026-05-05 Patch V1.1.1
    + Add Deep Sleep on esp32 + atmega after 60 sec on inactivity
    + Add Checkout system
    + Stripe implimentation
    + Add Display image (beta)
    + Boot time optimisation
    [numpad_v1.1.step]
